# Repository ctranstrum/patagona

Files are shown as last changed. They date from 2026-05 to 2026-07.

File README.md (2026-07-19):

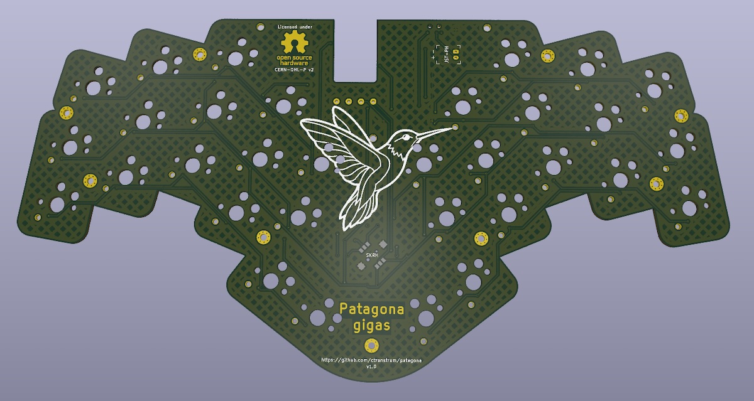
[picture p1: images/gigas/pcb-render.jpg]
Patagona gigas PCB


# Patagona Keyboards

Compact wireless ergo keyboards built around the [XIAO BLE][xiao] microcontroller
and running [ZMK][zmk] firmware with full [ZMK Studio][studio] support.
Named after the two species of giant hummingbird — the largest hummingbirds in the world.

## Features

- **Wireless** — internal LiPo battery; no cables required day to day
- **Live remapping** — ZMK Studio lets you customize your keymap over USB without recompiling firmware
- **Hotswap** — Kailh Choc sockets support both v1 and v2 switches; swap anytime
- **3D-printed case** — printable at home on any FDM printer, with split versions for smaller beds
- **Open hardware** — all source files included, licensed under [CERN-OHL-P-2.0][ohl]

## Patagona gigas

30–32 keys with a five-way joystick switch at the center,
within reach of either thumb for scroll, navigation, or mouse control.

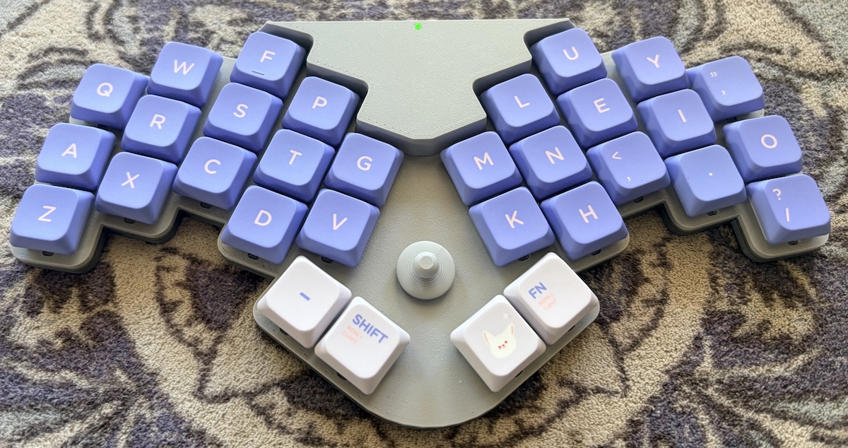
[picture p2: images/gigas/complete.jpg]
completed Patagona gigas build


[Build guide](BUILD-gigas.md) · [Printable case files][case-gigas] · [Firmware][firmware]

default Patagona gigas keymap

## Patagona chaski

40–42 keys for those who want the 3x6 layout and more thumb keys.

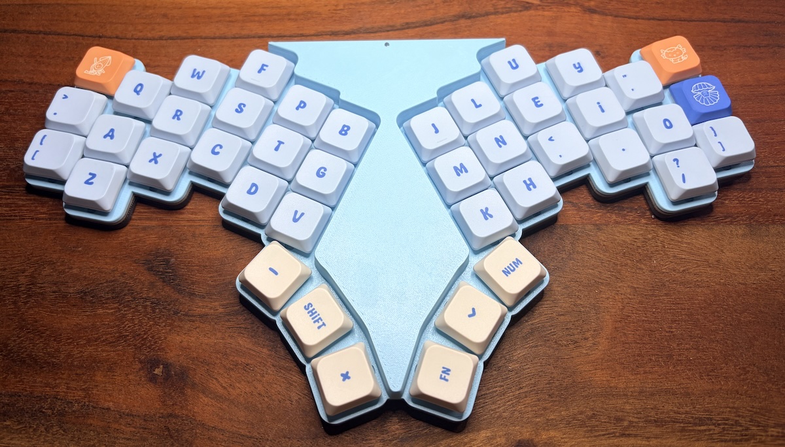
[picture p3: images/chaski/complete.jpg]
completed Patagona chaski build


[Build guide](BUILD-chaski.md) · [Printable case files][case-chaski] · [Firmware][firmware]

default Patagona chaski keymap

## Heritage

The [Patagona genus][patagona-wiki] is home to the two largest hummingbirds in the world.
_P. gigas_ is the migratory giant, ascending over 4,000 meters and traveling more than
4,000 km each way between the Chilean coast and the Peruvian Andes each year.
_P. chaski_ is its slightly larger but sedentary cousin.

These keyboards follow in the tradition of the original [Hummingbird design][pje66],
which used a XIAO SAMD21 and topped out at 30 keys
due to the maximum capacity of the 5×6 matrix allowed by the 11 pins on that board.
The Patagona boards use the XIAO BLE, whose NFC pads can be repurposed as GPIO —
adding two extra pins, enabling a 6×7 matrix and up to 42 keys.

[case-gigas]: https://github.com/ctranstrum/patagona/tree/main/cases/gigas#readme
[case-chaski]: https://github.com/ctranstrum/patagona/tree/main/cases/chaski#readme
[firmware]: https://github.com/ctranstrum/patagona-zmk
[ohl]: LICENSE.txt
[patagona-wiki]: https://en.wikipedia.org/wiki/Giant_hummingbird
[pje66]: https://github.com/PJE66/hummingbird
[studio]: https://zmk.dev/docs/features/studio
[xiao]: https://wiki.seeedstudio.com/XIAO_BLE/
[zmk]: https://zmk.dev

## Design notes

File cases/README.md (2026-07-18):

# Patagona Cases

For keyboard case files, see the keyboard-specific subdirectories:

- [Patagona chaski cases](chaski#readme)
- [Patagona gigas cases](gigas#readme)

## Five-way switch caps

This directory also contains two printable caps for the five-way switch used on the Patagona gigas:

| file | description |
| --- | --- |
| [joystick.stl](joystick.stl) | joystick-style cap (recommended) |
| [dpad.stl](dpad.stl) | dpad-style cap (experimental) |

Each cap has a corresponding `.cjs` source file that can be opened and edited at
[jscad.app](https://jscad.app) if you'd like to modify the design.

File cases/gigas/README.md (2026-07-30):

# Patagona Gigas Cases

> A quick note: these files were created through ergogen and can be
> modified and re-created if any changes are needed, which is great,
> except that the software is still a little bit buggy, so it doesn't
> make perfect STL files. Even though these can look a little strange,
> I have printed all of these files and they came out okay for me.

## Five-way switch cap

The five-way switch at the center of the Patagona gigas requires a cap to be usable.
The recommended cap is the [joystick style](../joystick.stl),
which fits snugly over the switch stem and provides a comfortable surface for navigation.

There is also an experimental [dpad style cap](../dpad.stl) available,
though after trying both, the joystick cap is the preferred option.

## Keyboard case files

### Full size printer

If you have access to your own 3D printer with a large print bed
or if you are sending the files away to be printed,
you will want to use the full size cases.

Print the following pieces:

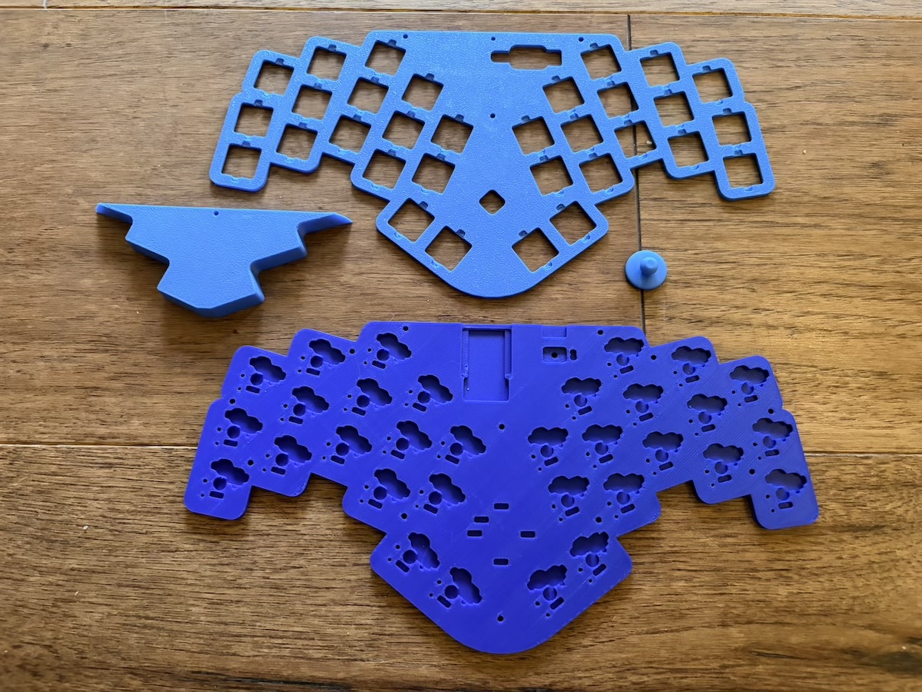
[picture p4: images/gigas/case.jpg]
case


- the bottom case
- your choice of one of the four top cases
- the battery cover
- the joystick knob

You can use the
[printer profile on makerworld](https://makerworld.com/en/models/3112971-patagona-gigas-keyboard-case#profileId-3510506)
or download the individual STL files:

| file | description |
| --- | --- |
| [bottom](bottom_case.stl) | installed below the PCB |
| [top 1+1](top_case_1_1.stl) | top case with one thumb key on each hand |
| [top 1+2](top_case_1_2.stl) | top case with one thumb key on the left and two on the right |
| [top 2+1](top_case_2_1.stl) | top case with two thumb keys on the left and one on the right |
| [top 2+2](top_case_2_2.stl) | top case with two thumb keys on each hand |
| [battery cover](battery_cover.stl) | above the top plate to cover the battery (do not print in resin) |
| [joystick knob](../joystick.stl) | knob for the central five-way switch |

Note that for best results on an FDM printer, the top plate and the battery cover should be printed upside down.

### Mini printer

If you have access to your own 3D printer
but it has a print bed too small for the full-size case,
you can print the case using these files.

Print the following pieces:

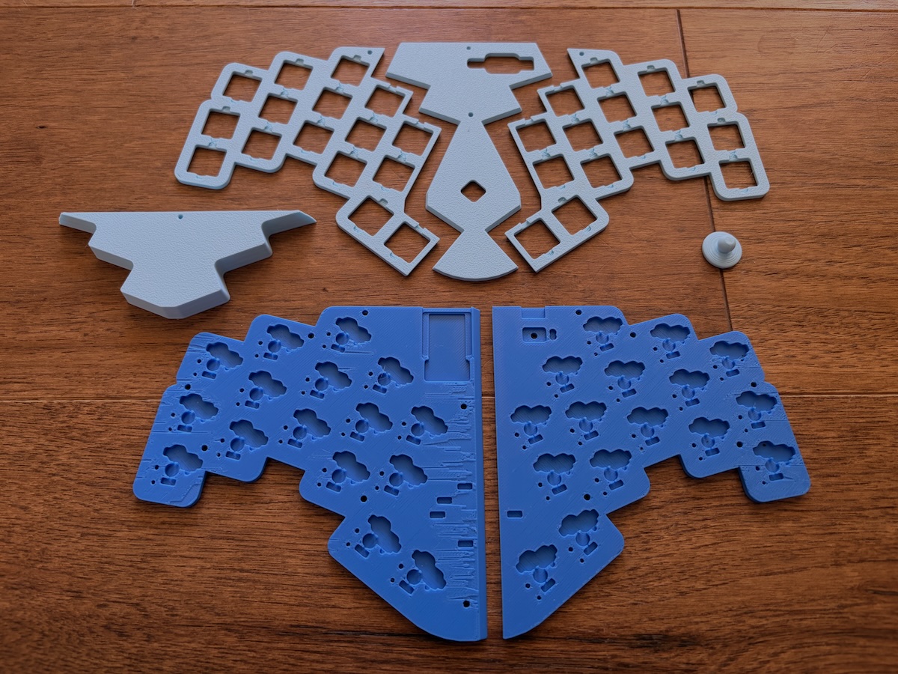
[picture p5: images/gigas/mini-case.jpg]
mini printer case


- the left and right bottom case
- the center top case
- your choice of one of the two top cases for the left hand
- your choice of one of the two top cases for the right hand
- the battery cover
- the joystick knob

You can use the
[printer profile on makerworld](https://makerworld.com/en/models/3112971-patagona-gigas-keyboard-case#profileId-3510558)
or download the individual STL files:

| file | description |
| --- | --- |
| [bottom left](bottom_case_cut_left.stl) | left bottom |
| [bottom right](bottom_case_cut_right.stl) | right bottom |
| [center](top_dovetail.stl) | center top case dovetail piece |
| [left 1](top_dovetail_left_1.stl) | left top case piece with one thumb key |
| [left 2](top_dovetail_left_2.stl) | left top case piece with two thumb keys |
| [right 1](top_dovetail_right_1.stl) | right top case piece with one thumb key |
| [right 2](top_dovetail_right_2.stl) | right top case piece with two thumb keys |
| [battery cover](battery_cover.stl) | above the top plate to cover the battery (do not print in resin) |
| [joystick knob](../joystick.stl) | knob for the central five-way switch |

Note that for best results on an FDM printer, the top plate and the battery cover should be printed upside down.

### Rectangular snap-fit case

I've also created an alternative case that uses fewer screws and instead relies on a snap-fit design
to remain securely fastened without sacrificing any additional height compared to the original sandwich design.

Unlike the sandwich-style cases, it is available only for full-size printer beds.

Print the following pieces:

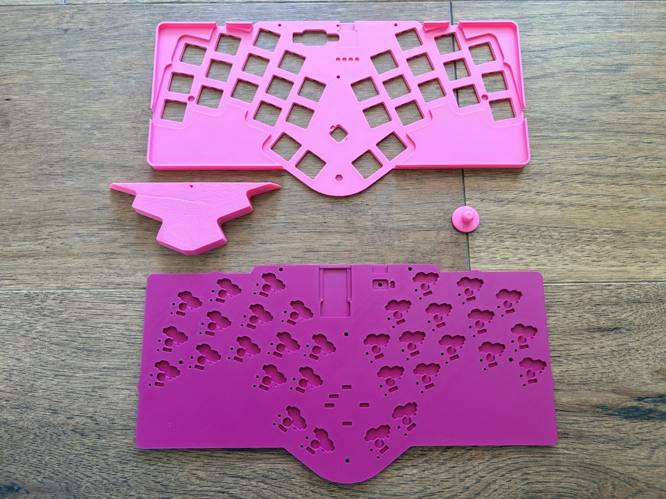
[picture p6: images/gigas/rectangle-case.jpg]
rectangle case


- the bottom case
- your choice of one of the four top cases
- the battery cover
- the joystick knob

You can use the
[printer profile on makerworld](https://makerworld.com/en/models/3112971-patagona-gigas-keyboard-case#profileId-3510571)
or download the individual STL files:

| file | description |
| --- | --- |
| [bottom](rectangle_bottom_case.stl) | bottom case |
| [top 1+1](rectangle_top_case_1_1.stl) | top case with one thumb key on each hand |
| [top 1+2](rectangle_top_case_1_2.stl) | top case with one thumb key on the left and two on the right |
| [top 2+1](rectangle_top_case_2_1.stl) | top case with two thumb keys on the left and one on the right |
| [top 2+2](rectangle_top_case_2_2.stl) | top case with two thumb keys on each hand |
| [battery cover](battery_cover.stl) | above the top case to cover the battery (do not print in resin) |
| [joystick knob](../joystick.stl) | knob for the central five-way switch |

Note that it is especially important when printing this case style on an FDM printer to place the top case
upside down in the slicer so that the top surface of the case is in direct contact with the print bed.
Otherwise you are going to have a real struggle with support removal.

## Print quality hints

For best results, use the
[printer profile on makerworld](https://makerworld.com/en/models/3112971-patagona-gigas-keyboard-case).
It has been optimized with the top pieces already placed upside down on the print bed
as well as having the layer height set to 0.1mm to ensure the best fit for the keyswitches.

When printing this case,
it should be noted that the battery cover is designed
to have heat-set inserts melted into it,
so it is not recommended to print using a resin printer
or using a material that cannot be melted easily,
unless you plan on altering the case design to use another method
to fasten the case together.

All other parts of the case can be printed in whatever material you like.

For FDM printing,
the top case and the battery cover are best printed upside down,
so that the visible part of the case is against the print bed,
giving the best top surface and requiring minimal supports to print.

If you are having trouble with some of the raised areas sagging during printing,
you can try to enable supports.
While I was able to tune my printer to get great results without supports,
if your printer is not well calibrated,
it may be worth it to enable supports and spend a little time
post-processing the prints to remove the supports prior to assembly.

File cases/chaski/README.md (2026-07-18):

# Patagona Chaski Cases

> A quick note: these files were created through ergogen and can be
> modified and re-created if any changes are needed, which is great,
> except that the software is still a little bit buggy, so it doesn't
> make perfect STL files. Even though these can look a little strange,
> I have printed all of these files and they came out okay for me.

## Keyboard case files

### Full size printer

If you have access to your own 3D printer with a large print bed
or if you are sending the files away to be printed,
you will want to use the full size cases:

| file | description |
| --- | --- |
| [bottom](bottom_case.stl) | installed below the PCB |
| [top 2+2](top_case_2_2.stl) | top case with two thumb keys on each hand |
| [top 2+3](top_case_2_3.stl) | top case with two thumb keys on the left and three on the right |
| [top 3+2](top_case_3_2.stl) | top case with three thumb keys on the left and two on the right |
| [top 3+3](top_case_3_3.stl) | top case with three thumb keys on each hand |
| [battery cover](battery_cover.stl) | above the top plate to cover the battery (do not print in resin) |

Note that for best results on an FDM printer, the top plate and the battery cover should be printed upside down.

### Mini printer

If you have access to your own 3D printer
but it has a print bed too small for the full-size case,
you can print the 3-part (plus the battery cover) top case:

| file | description |
| --- | --- |
| [center](top_dovetail.stl) | center top case dovetail piece |
| [left 2](top_dovetail_left_2.stl) | left top case piece with two thumb keys |
| [left 3](top_dovetail_left_3.stl) | left top case piece with three thumb keys |
| [right 2](top_dovetail_right_2.stl) | right top case piece with two thumb keys |
| [right 3](top_dovetail_right_3.stl) | right top case piece with three thumb keys |
| [battery cover](battery_cover.stl) | above the top plate to cover the battery (do not print in resin) |

Note that for best results on an FDM printer, the top plate and the battery cover should be printed upside down.

### Rectangular snap-fit case

I've also created an alternative case that uses fewer screws and instead relies on a snap-fit design
to remain securely fastened without sacrificing any additional height compared to the original sandwich design.

Unlike the sandwich-style cases, it is available only for full-size printer beds.

| file | description |
| --- | --- |
| [bottom](rectangle_bottom_case.stl) | bottom case |
| [top 2+2](rectangle_top_case_2_2.stl) | top case with two thumb keys on each hand |
| [top 2+3](rectangle_top_case_2_3.stl) | top case with two thumb keys on the left and three on the right |
| [top 3+2](rectangle_top_case_3_2.stl) | top case with three thumb keys on the left and two on the right |
| [top 3+3](rectangle_top_case_3_3.stl) | top case with three thumb keys on each hand |
| [battery cover](battery_cover.stl) | above the top case to cover the battery (do not print in resin) |

Note that it is especially important when printing this case style on an FDM printer to place the top case
upside down in the slicer so that the top surface of the case is in direct contact with the print bed.
Otherwise you are going to have a real struggle with support removal.

## Print quality hints

When printing this case,
it should be noted that the battery cover is designed
to have heat-set inserts melted into it,
so it is not recommended to print using a resin printer
or using a material that cannot be melted easily,
unless you plan on altering the case design to use another method
to fasten the case together.

All other parts of the case can be printed in whatever material you like.

For FDM printing,
the top case and the battery cover are best printed upside down,
so that the visible part of the case is against the print bed,
giving the best top surface and requiring minimal supports to print.

If you are having trouble with some of the raised areas sagging during printing,
you can try to enable supports.
While I was able to tune my printer to get great results without supports,
if your printer is not well calibrated,
it may be worth it to enable supports and spend a little time
post-processing the prints to remove the supports prior to assembly.

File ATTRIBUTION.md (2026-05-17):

# Graphics images

The hummingbird image on the PCB is
by Cimrin from [Noun Project](https://thenounproject.com/browse/icons/term/hummingbird/) (CC BY 3.0)

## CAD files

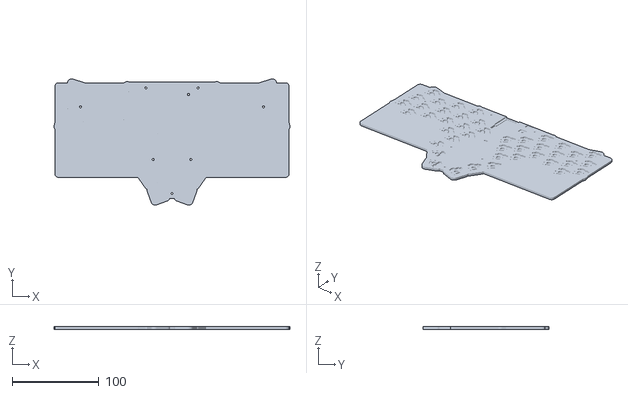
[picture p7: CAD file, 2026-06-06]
cases/chaski/rectangle_bottom_case.stl
271.6 x 145.2 x 3.00

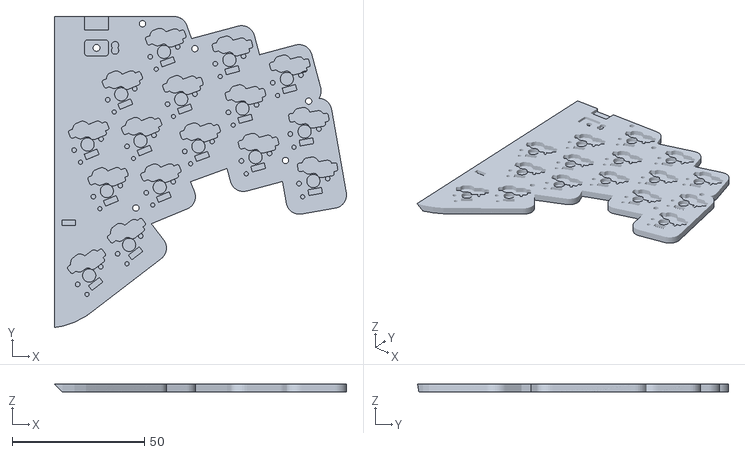
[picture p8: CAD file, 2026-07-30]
cases/gigas/bottom_case_cut_right.stl
110.3 x 117.4 x 3.00

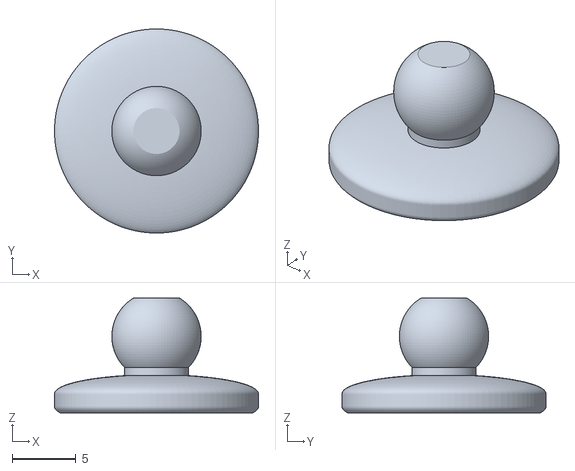
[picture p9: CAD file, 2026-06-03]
cases/joystick.stl
16.0 x 16.0 x 9.00

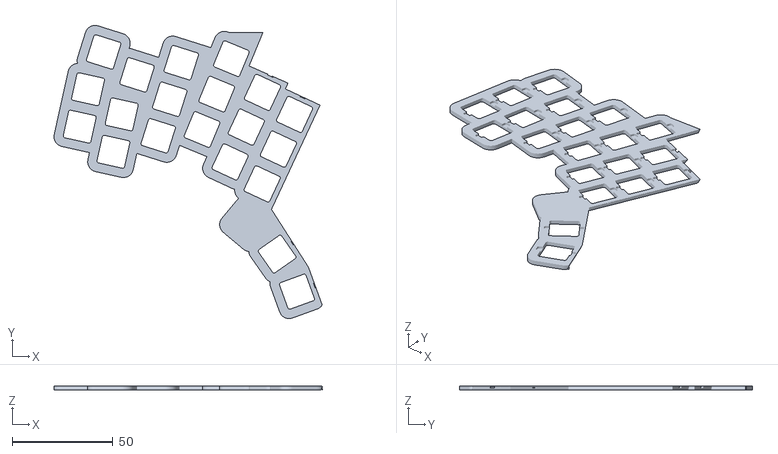
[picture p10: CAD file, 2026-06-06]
cases/chaski/top_dovetail_left_2.stl
161.5 x 145.2 x 2.20

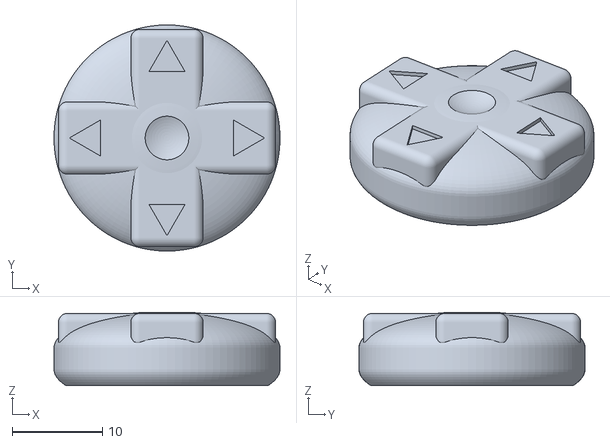
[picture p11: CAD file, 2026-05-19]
cases/dpad.stl
25.0 x 25.0 x 8.12

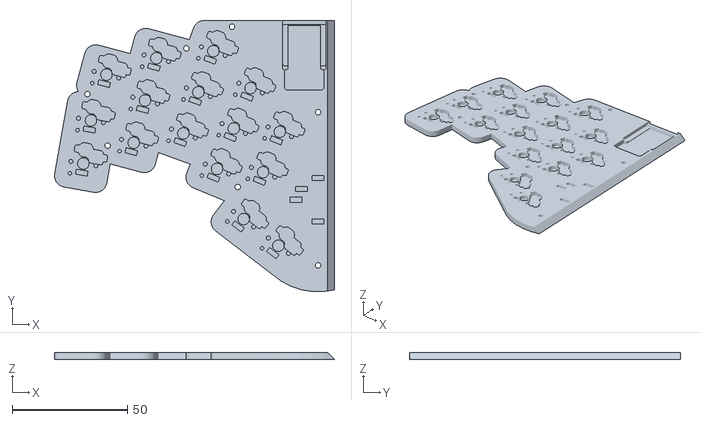
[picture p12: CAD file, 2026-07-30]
cases/gigas/bottom_case_cut_left.stl
121.5 x 117.7 x 3.00

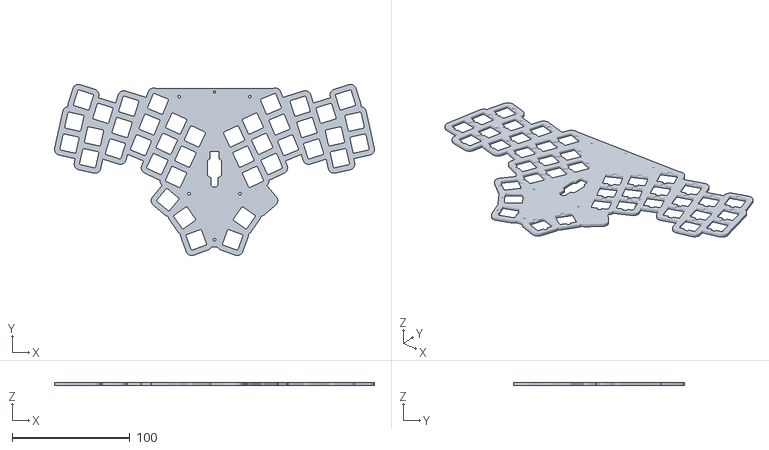
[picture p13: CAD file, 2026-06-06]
cases/chaski/top_case_3_2.stl
271.6 x 145.2 x 2.20

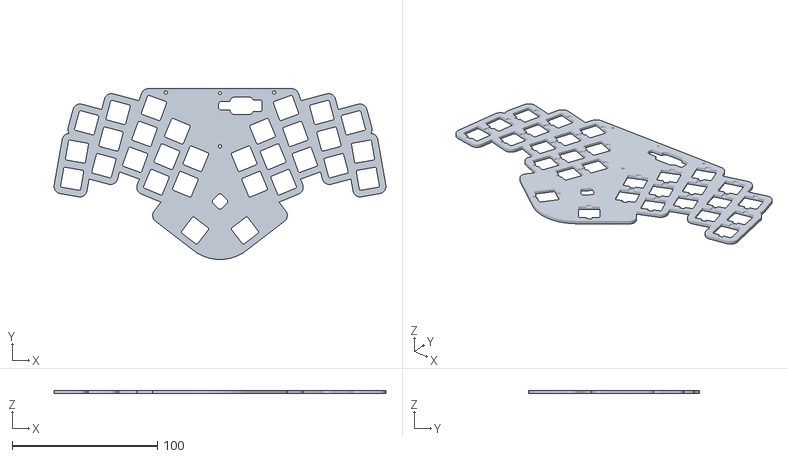
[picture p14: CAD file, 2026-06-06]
cases/gigas/top_case_1_1.stl
228.8 x 117.7 x 2.20

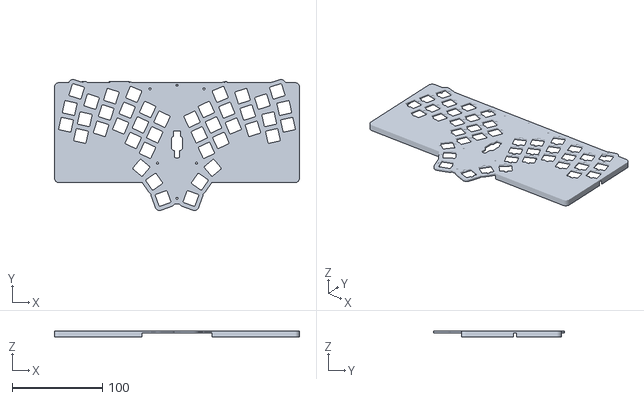
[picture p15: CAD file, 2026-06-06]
cases/chaski/rectangle_top_case_3_3.stl
271.7 x 145.2 x 6.80

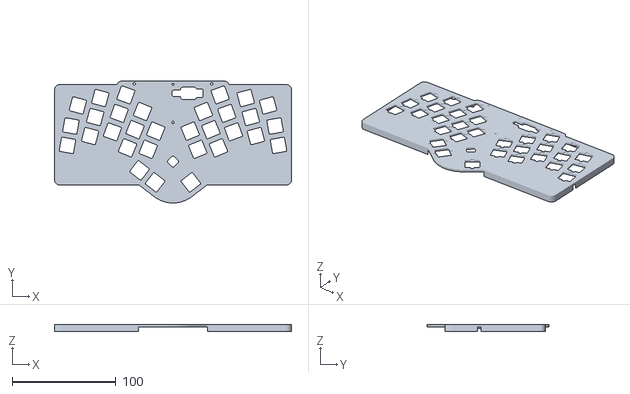
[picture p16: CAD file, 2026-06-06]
cases/gigas/rectangle_top_case_2_1.stl
228.8 x 117.7 x 6.80

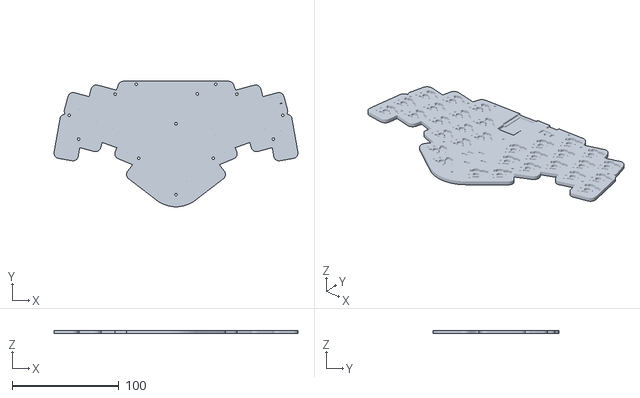
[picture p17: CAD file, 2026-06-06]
cases/gigas/bottom_case.stl
228.8 x 117.7 x 3.00

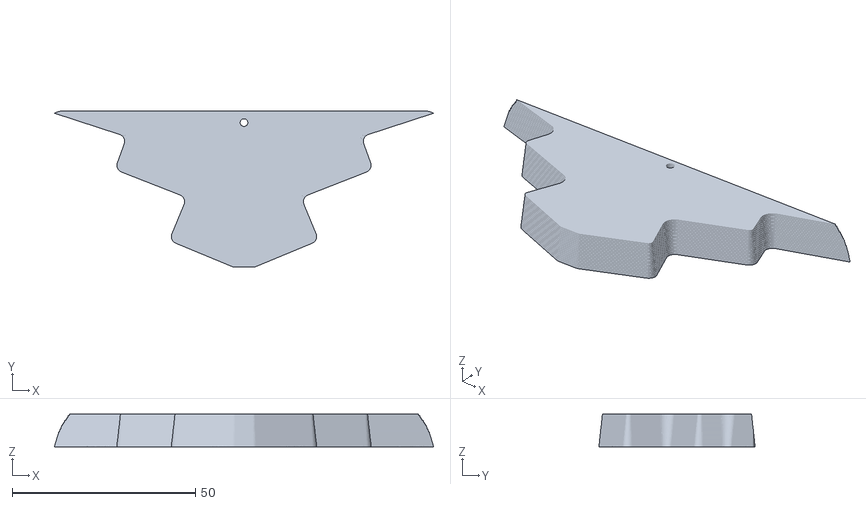
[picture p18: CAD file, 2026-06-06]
cases/gigas/battery_cover.stl
103.5 x 42.7 x 9.00

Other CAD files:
cases/chaski/rectangle_top_case_2_2.stl
cases/chaski/top_case_2_2.stl
cases/gigas/rectangle_top_case_1_2.stl
cases/chaski/rectangle_top_case_3_2.stl
cases/gigas/rectangle_top_case_1_1.stl
cases/chaski/rectangle_top_case_2_3.stl
cases/chaski/battery_cover.stl
cases/chaski/bottom_case.stl
cases/chaski/top_case_2_3.stl
cases/chaski/top_case_3_3.stl
cases/chaski/top_dovetail.stl
cases/chaski/top_dovetail_left_3.stl
cases/chaski/top_dovetail_right_2.stl
cases/chaski/top_dovetail_right_3.stl
cases/gigas/rectangle_bottom_case.stl
cases/gigas/rectangle_top_case_2_2.stl
cases/gigas/top_case_1_2.stl
cases/gigas/top_case_2_1.stl
cases/gigas/top_case_2_2.stl
cases/gigas/top_dovetail.stl
cases/gigas/top_dovetail_left_1.stl
cases/gigas/top_dovetail_left_2.stl
cases/gigas/top_dovetail_right_1.stl
cases/gigas/top_dovetail_right_2.stl

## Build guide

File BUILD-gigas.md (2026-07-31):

# Patagona gigas Build Guide

If this is your first time building a custom keyboard,
you should do two things before attempting this build.

- watch a few [soldering][how-to-solder] [tutorials][soldering101]
- read through a detailed build guide like
  the one for the [splitkb.com Aurora Series][splitkb-build-guide]

The remainder of this build guide will assume a basic familiarity with the process
and will only hit upon specific items that may be different or important to note while
building the Patagona gigas.

## Bill of materials

| Qty | Description |
| --- | --- |
| 1 | Gigas PCB (can be printed by uploading the [zip file][gigas-gerber] to [JLC][jlcpcb]) |
| 3 | [3D printed cases][case] |
| 1 | [XIAO BLE][xiao] |
| 1 | [SMD 5x5x3 tactile switch][reset] for the reset button (similar to [this][pts526] or [this][ts18]) |
| 1 | [Alps SSSS811101 SPDT slide switch][power] for the battery on/off |
| 1 | [3.7v 400mAh 802525 LiPo battery][battery] or smaller (max internal space: 8x28x29mm) |
| 1 | [JST PH-2 battery jack][jst] |
| 1 | Alps Alpine [SKRHADE010 five-way switch][fiveswitch] |
| 30-32  | SOD-123 [1N4148W SMD diodes][sod123] |
| 30-32  | Kailh [choc hot swap sockets][sockets] |
| 30-32  | [Choc v1][chocv1] or [v2 switches][chocv2] of your choice |
| 30-32  | [Low profile choc v1][chockeycaps] or [v2 keycaps][mxkeycaps] of your choice |
| 9 (3)  | [M2 x 6mm countersunk screws][screws6mm] |
| 9 (3)  | [M2 hex nuts][hexnuts] |
| 3 | [M2 x 10mm countersunk screws][screws10mm] |
| 3 | [M2 heat-set inserts 3mm x 3mm][heatset] |
| 10 (8) | [6mm x 1.5mm bumpons][bumpons] |
| ~1cm | [1.75mm transparent 3D printer filament][filament] for the "fiber optic" led light guide |
| 4 | short (1-2cm) pieces of [26 gauge electrical wire][wire] |

**Note**: When assembling a gigas build in a rectangle case, you will use fewer 6mm screws, hex nuts, and bumpons.
The quantities for the rectangle case are given in parentheses.

## Useful equipment

You will need:

- a [soldering iron][pinecil]
- some [good quality solder][kester]
- precision tweezers
- wire cutter / stripper

You should ideally have access to:

- a [heat-set insert tool][heatsettool]
- a decent hands-free magnifying glass
- isopropyl alcohol and an old toothbrush

## Getting the PCB

The PCB can be easily ordered from a circuit board manufacturer with an online store.
I used [JLC][jlcpcb] because--at least at the time of my order--their prices are unbeatable.

To order, you can simply upload the [gerber zip file][gigas-gerber] to their website,
accept all of the defaults, and wait a week or two for the boards to arrive.

However, the minimum order at JLC is 5 copies, so you'll likely end up
with 4 extra PCBs. I don't really have any advice for what to do with
the extras, but you maybe could give one to a friend!

A couple items that you may want to customize:

- the color of the board; I printed mine in black
- HASL can be lead-free if you are also using lead-free solder, or you can splurge for ENIG, but it's definitely not required

gigas pcb render

## Getting the case

If you have access to a 3D printer, the [case][case] is very easy to print yourself.

If you don't have your own printer, no worries.
You will probably want to send in your print order around the same time you order the PCB.
I've used [JLC][jlc3dp] in the past with good results.

Just remember that you should print the battery cover
in nylon or PLA rather than resin,
though all other parts of the case can be printed in resin.
The reason for this is that the design calls for heat-set inserts
to be melted into that piece, and resin doesn't work for that.

## General soldering order

Although you can work in any order you prefer,
I like to start with the smaller components, then move to the larger,
and finish with bulky items that go on the top of the board.

So, the order I install:

### Installed on the bottom of the board

- diodes
- hotswap sockets
- power switch
- reset switch
- xiao
- reset and battery wire connections to xiao

### Installed on the top of the board

- jst (inserted from the top, soldered from the bottom)
- five-way switch (the only component installed entirely from the top of the board)

## Step-by-step instructions

Let's get started, shall we?

### Solder the diodes

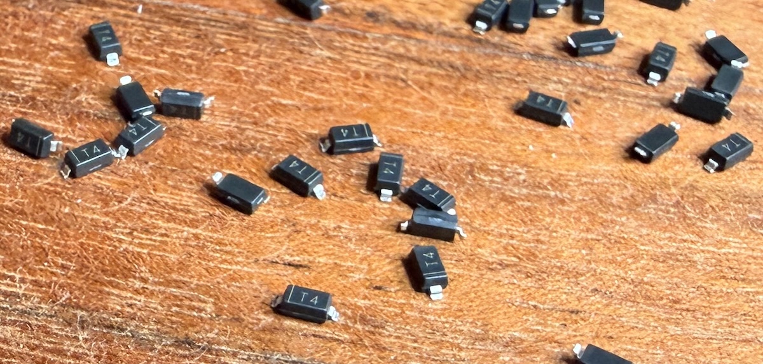
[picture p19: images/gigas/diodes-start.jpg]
diodes and PCB ready to begin soldering


Diodes are directional components, and must be soldered in the correct orientation.

To determine the orientation, look for a line printed on one edge of the diode.
You may need to use a magnifier glass and adjust the angle of light hitting the diode
in order to see it clearly.
Once you find the line on the diode, you can align it with the silk-screened line on the PCB,
and then solder with both lines on the same side.

All diodes are installed in roughly the same direction on the board, with the line on the right.

To easily install a diode, first place a small amount of solder onto one of the diode pads.

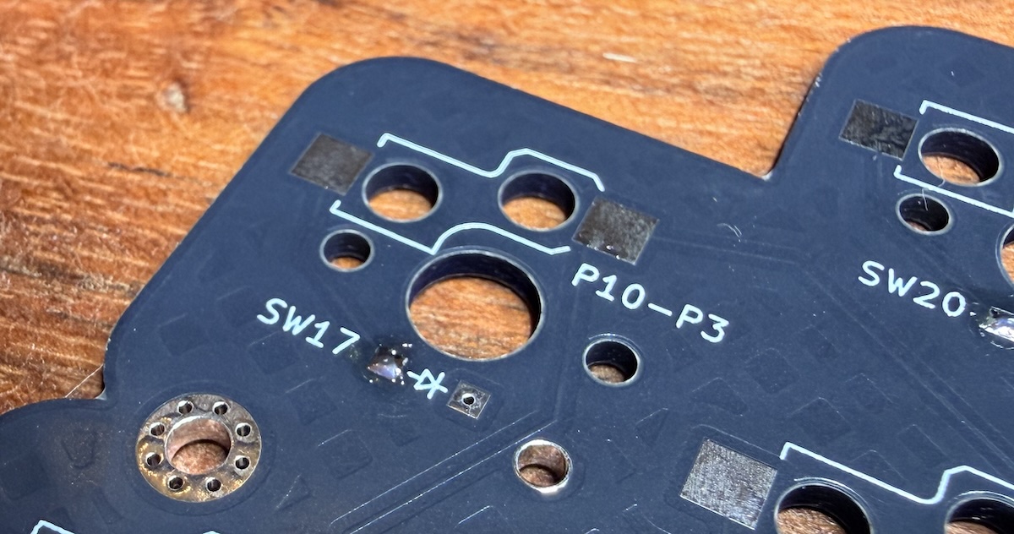
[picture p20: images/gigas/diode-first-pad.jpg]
diode with one pad soldered, ready to place


Then grab the diode with tweezers and orient it correctly.
Reheat the soldered pad, then slide the diode into place.
Remove the heat, and when the solder cools, release the diode.

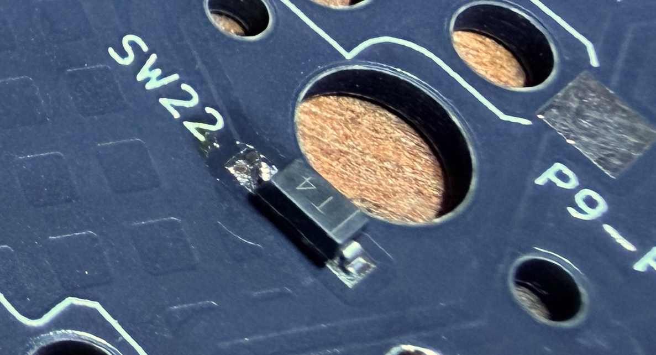
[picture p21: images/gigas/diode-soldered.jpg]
diode with both legs soldered in place


With one leg installed, you can apply solder to the other leg.

Complete all diodes, being sure to double-check that they are all oriented
correctly and both legs are soldered before moving to the next step.

### Solder the hotswap sockets

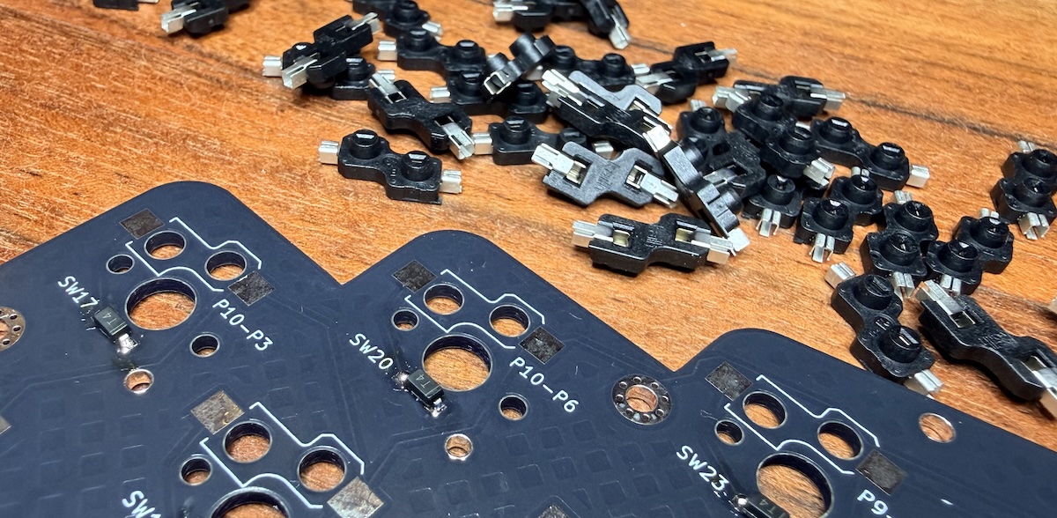
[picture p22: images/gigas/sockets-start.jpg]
sockets ready to be soldered to the PCB


While hotswap sockets will work the same way electrically no matter which way they are installed,
the tolerances of the case are such that you should take care to install these
according to the markings on the PCB as well.

In the following picture, the blue box on SW20 shows the silkscreen line before
a hotswap socket is installed, the green box on SW22 shows a hotswap socket in the
correct orientation where the silkscreen line is mostly hidden by the edges of the socket,
and the red box on SW19 shows an incorrectly oriented
hotswap socket, where the silkscreen line is clearly visible poking out around the
angled edges of the socket.

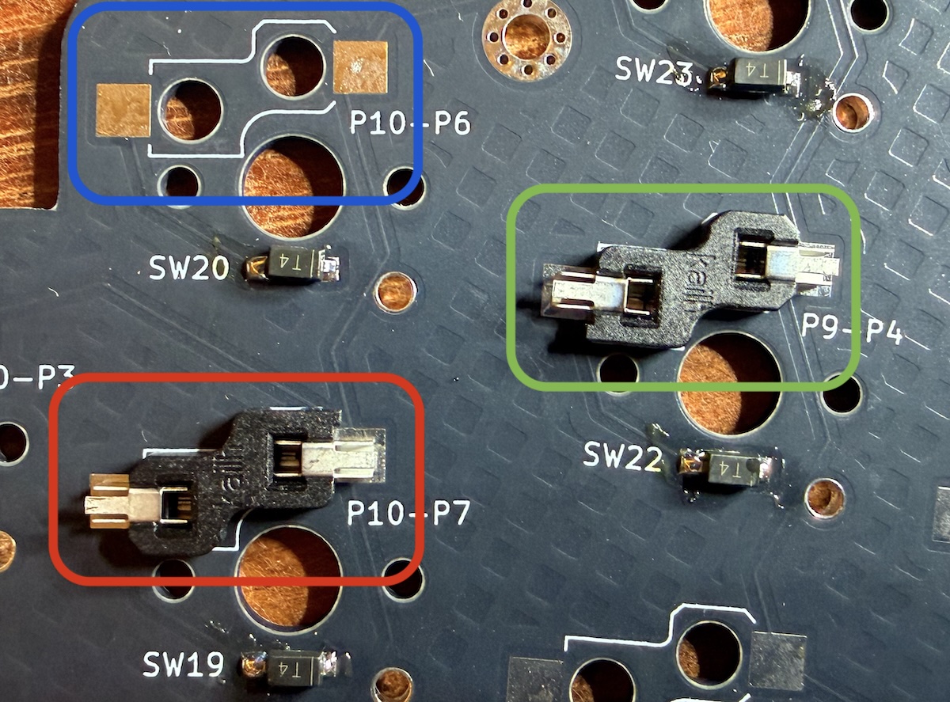
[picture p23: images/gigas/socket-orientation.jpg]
three sockets showing correct and incorrect orientation


Place the hotswap socket into the PCB holes,
being sure that the silkscreen on the PCB matches the orientation of the socket,
then apply solder to one of the legs.

This will take a lot more solder than the diode did, but be careful not to get carried away.
The solder should not overflow the pad or rise above the socket.

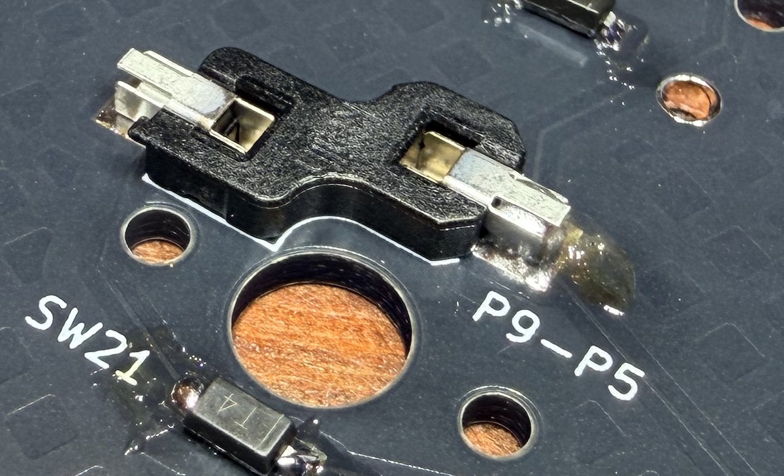
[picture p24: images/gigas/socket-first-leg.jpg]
hotswap socket with first leg soldered


Once done, use tweezers to hold the socket in place until the solder cools.

Flip the board around and solder the other pad.

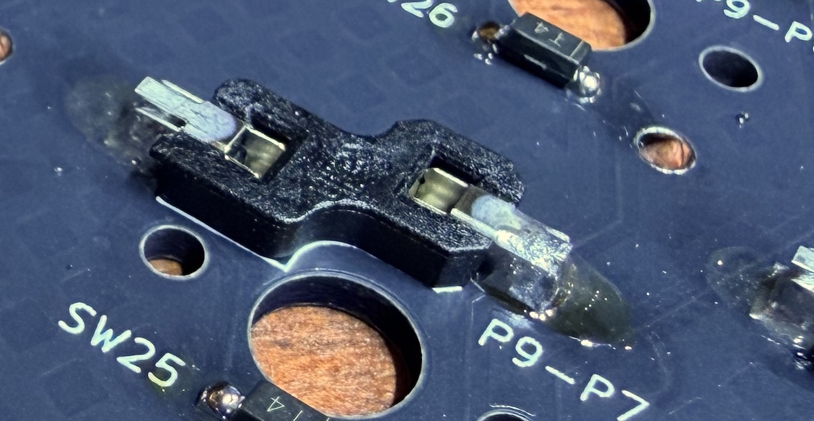
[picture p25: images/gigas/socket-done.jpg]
hotswap socket with both legs soldered


Solder all the sockets on the board.

### Solder the power switch

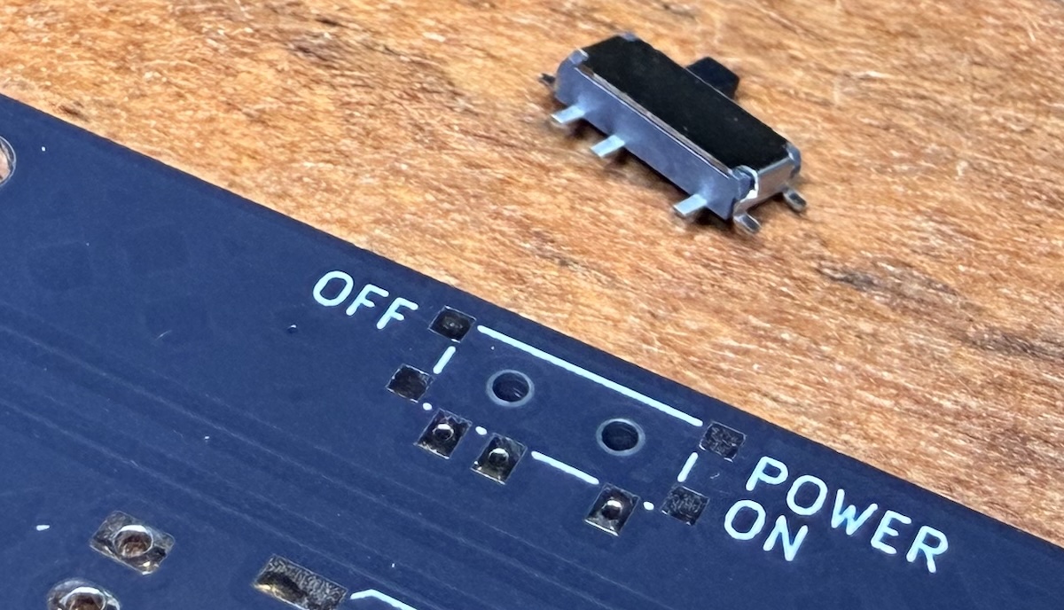
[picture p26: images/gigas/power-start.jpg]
power switch ready to be soldered


To solder the power switch, first apply a bit of solder to one of the pads.

Holding the power switch in place with tweezers, reheat the soldered pad
and align the power switch. Remove the heat, and release the power switch
only after the solder has cooled.

Once satisfied with the placement, solder each of the other pads, being very careful
not to allow the solder to connect neighboring pads.

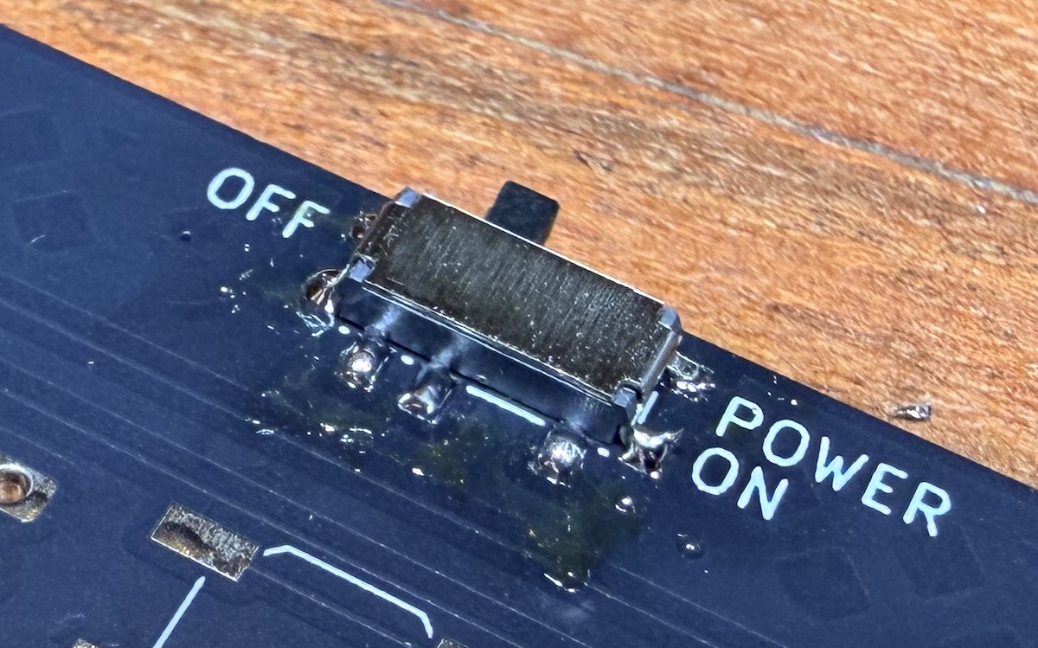
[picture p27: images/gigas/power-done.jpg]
power switch fully soldered


### Solder the reset switch

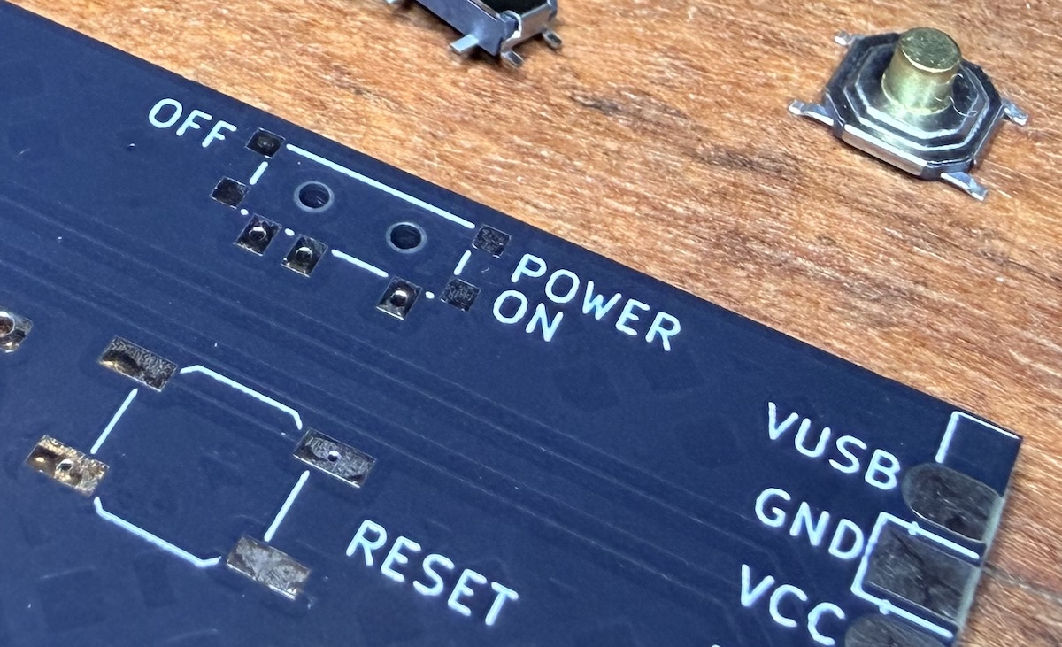
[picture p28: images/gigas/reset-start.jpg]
reset switch ready to be soldered


The reset switch follows the same process,
though it can require a little more attention to align it correctly.

Apply solder to one pad,
use tweezers to slide the reset switch into place while reheating the solder,
and remove the heat when you are satisfied with the alignment.

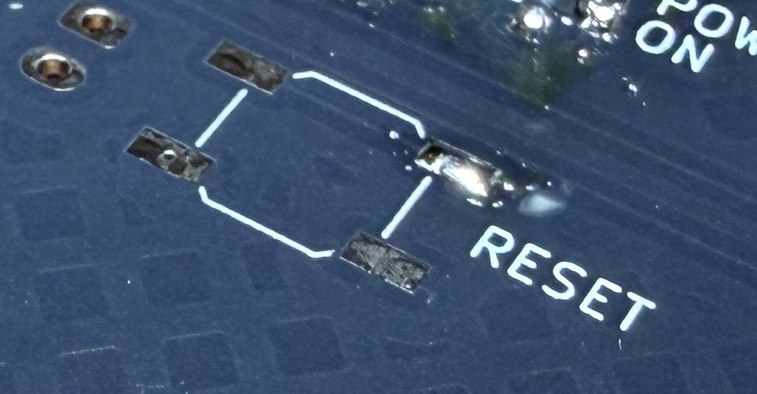
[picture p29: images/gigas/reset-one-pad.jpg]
first pad ready to receive the reset switch


Complete the remaining pads.

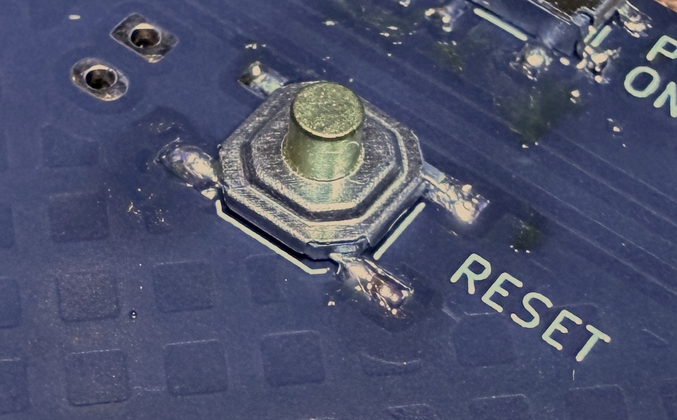
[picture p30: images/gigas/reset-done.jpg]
reset switch fully soldered


### Solder the xiao

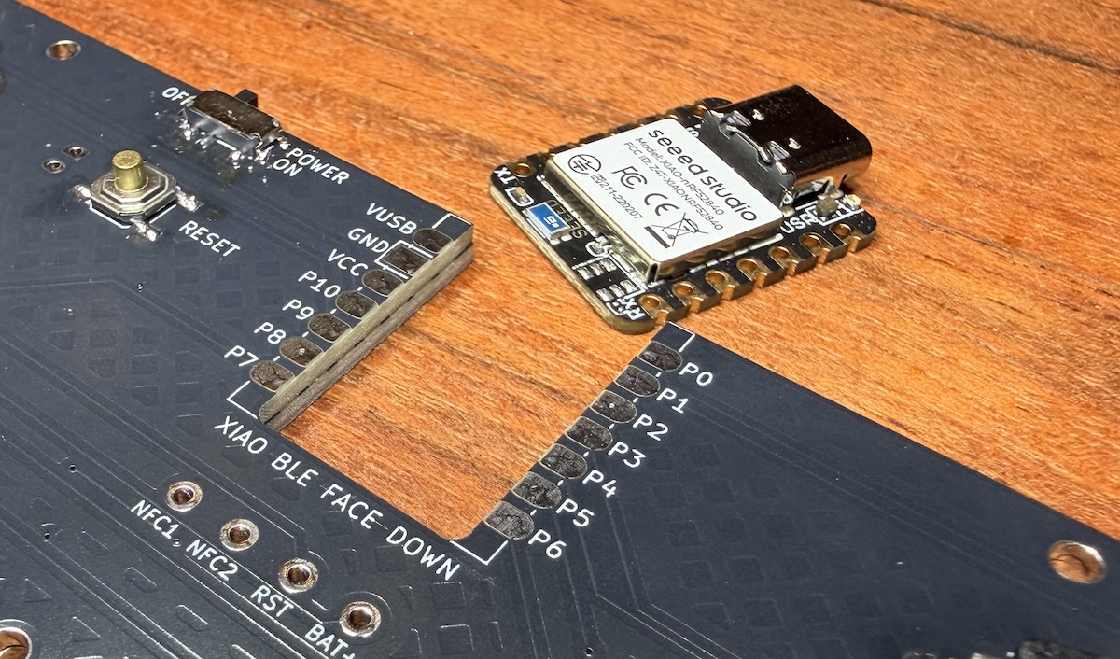
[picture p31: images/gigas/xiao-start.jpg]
PCB elevated for installation of the XIAO


The xiao is installed upside down,
with the components on top of the xiao extending
into and beyond the space of the PCB.

Because of this, the xiao will need a little space under it,
since it is thicker than the PCB.
I like to stack another board below it to provide that space,
but any method of elevating the board will work.

Begin by placing a little solder on one of the corner pads.
Put the xiao in place, reheat the soldered pad,
and ensure the correct placement of the xiao before removing the heat.

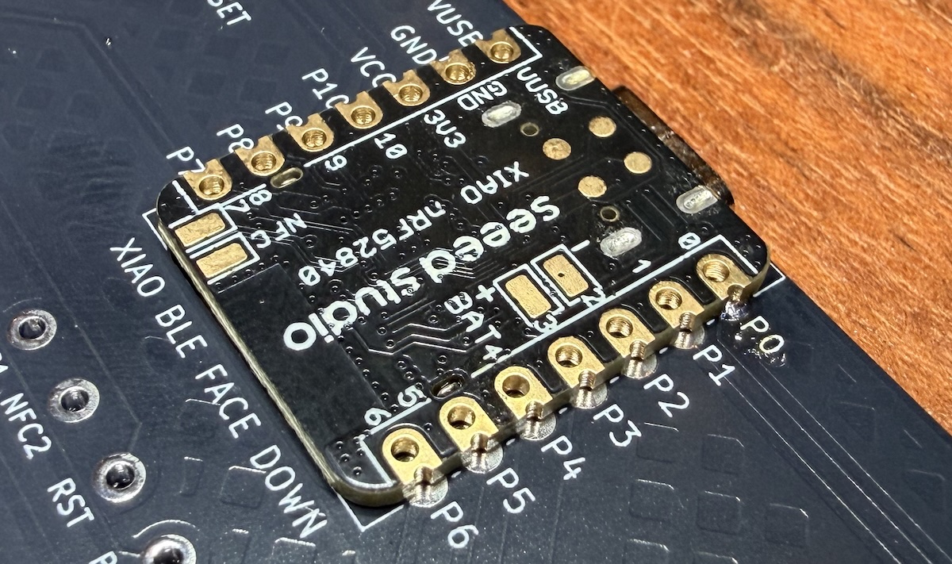
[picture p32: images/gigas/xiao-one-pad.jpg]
xiao with one corner pad soldered


Once the solder cools and you are satisfied that the xiao is in the correct place,
solder the opposite corner. It can be a little tricky to get heat on both the
pad of the PCB as well as the xiao's pad, so take your time, use plenty of heat,
and wait until you see the solder moving below the xiao and filling a bit of the
through-hole.

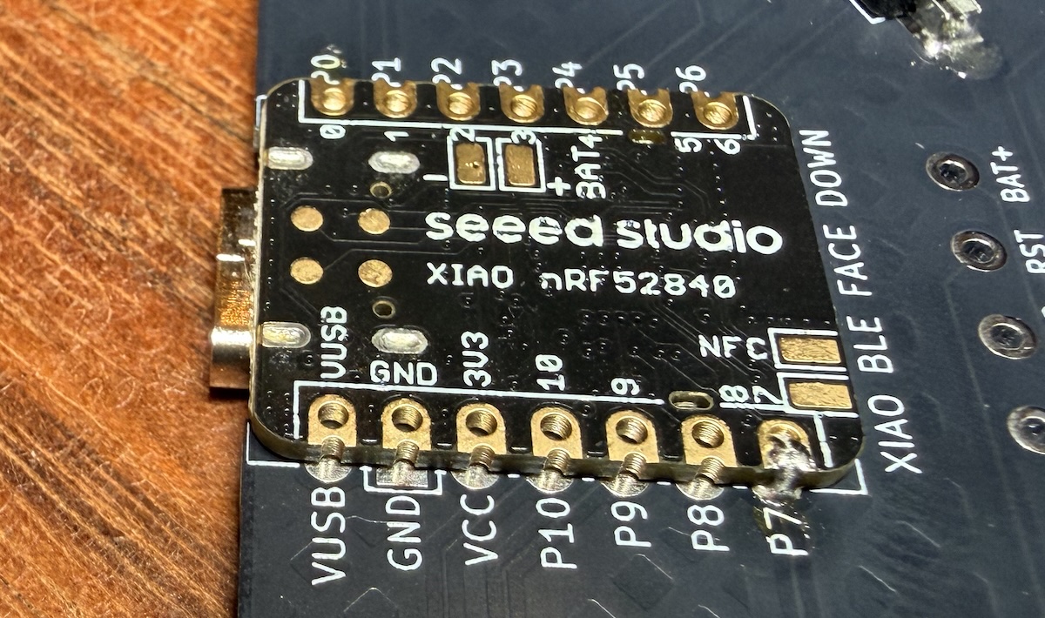
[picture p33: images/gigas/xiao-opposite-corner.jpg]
xiao with opposite corner pad soldered


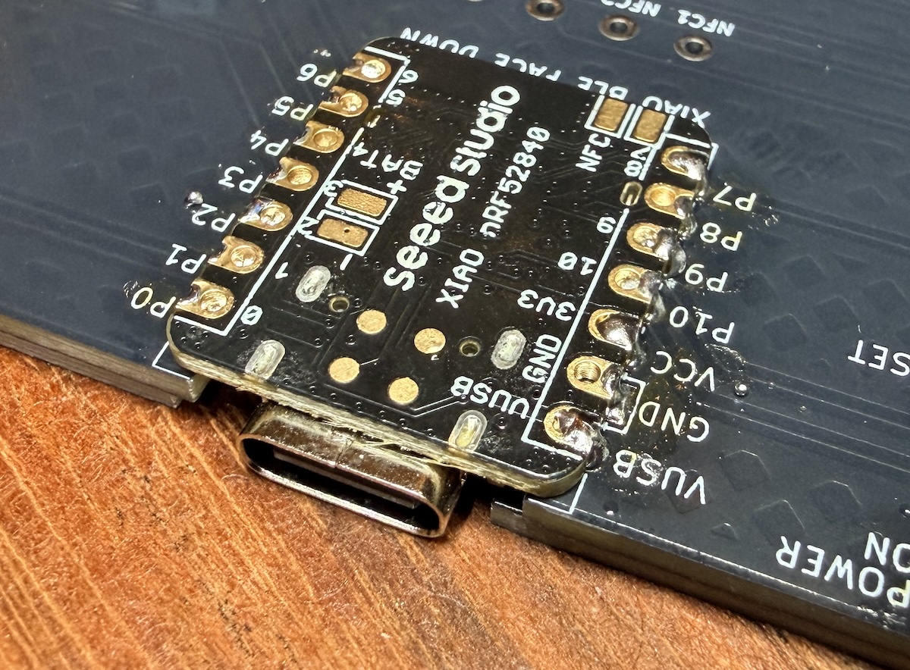
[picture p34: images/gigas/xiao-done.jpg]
xiao fully soldered to PCB


Repeat this process until all the pads of the xiao are soldered well to the board.
I also usually re-solder the first pad I did,
since it likely has the least amount of solder on it compared to all the others.

### Solder the xiao connections

Begin by cutting a short piece of wire a little bit longer than needed to connect the pad to the through-hole.

For the power connection, this connects the BAT+ hole on the PCB with the BAT+ pad on the back of the xiao.

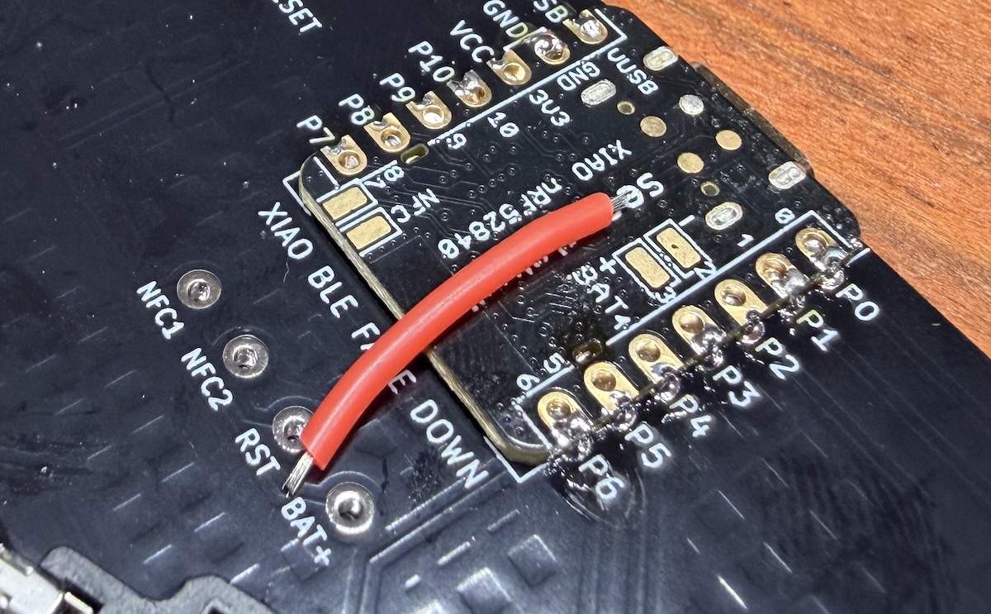
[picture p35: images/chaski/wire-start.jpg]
BAT+ wire ready to connect xiao to PCB


Trim about 1.5mm of shielding off each end of the wire, and then solder the wire.
I like to start with the end on the xiao's pad, and once that is in place,
stick the other end into the through hole and solder there as well.

The reset wire connects the RST hole on the PCB to the unlabeled reset pad on the back of the xiao.

Even though it's unlabeled, it's not difficult to find.
There are four circular pads near the USB port at the top of the xiao.

Location of the RST pad on the XIAO BLE:

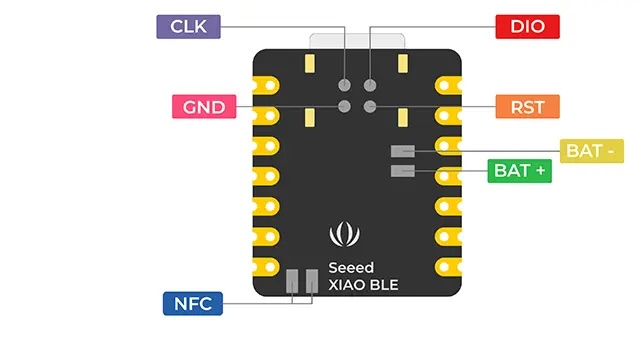
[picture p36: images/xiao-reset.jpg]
location of RST pad on the back of the XIAO BLE


Install it using the same method as the BAT+ wire.

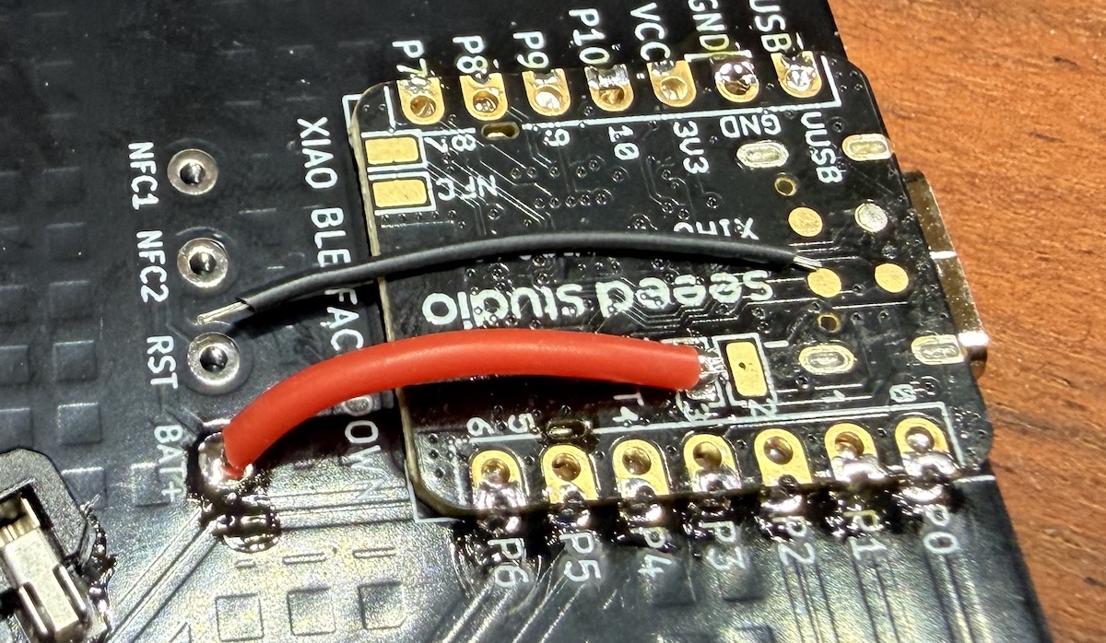
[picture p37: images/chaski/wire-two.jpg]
RST wire connecting xiao to PCB


The final two wires connect the NFC1 and NFC2 holes on the PCB to the NFC pads on the back of the xiao.
The xiao has two NFC pads near each other, though only one of them is labeled.
Install these wires so that they run parallel to each other:
NFC2 on the PCB connects to the right NFC pad on the xiao,
and NFC1 on the PCB connects to the left NFC pad on the xiao.
Install NFC2 first, then NFC1.

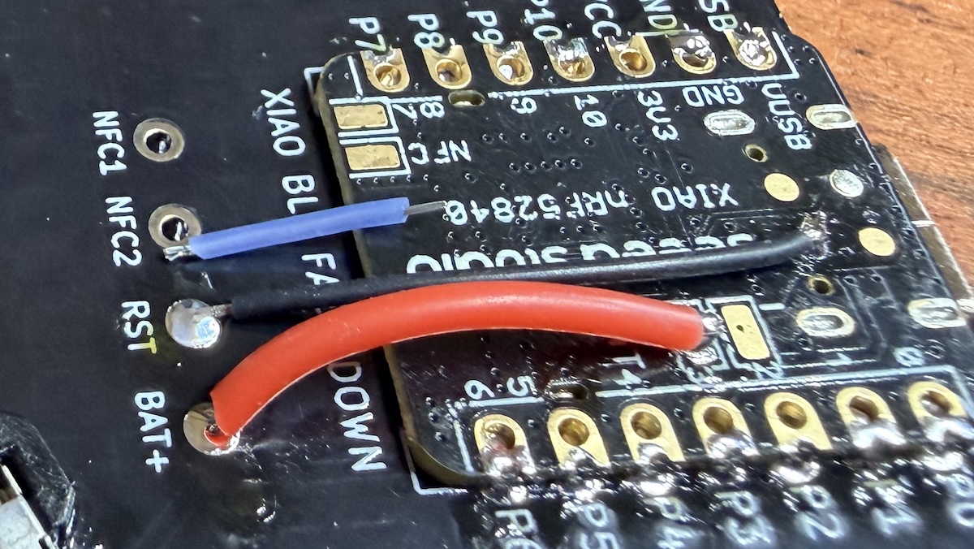
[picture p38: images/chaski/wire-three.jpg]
NFC2 wire cut and ready to install


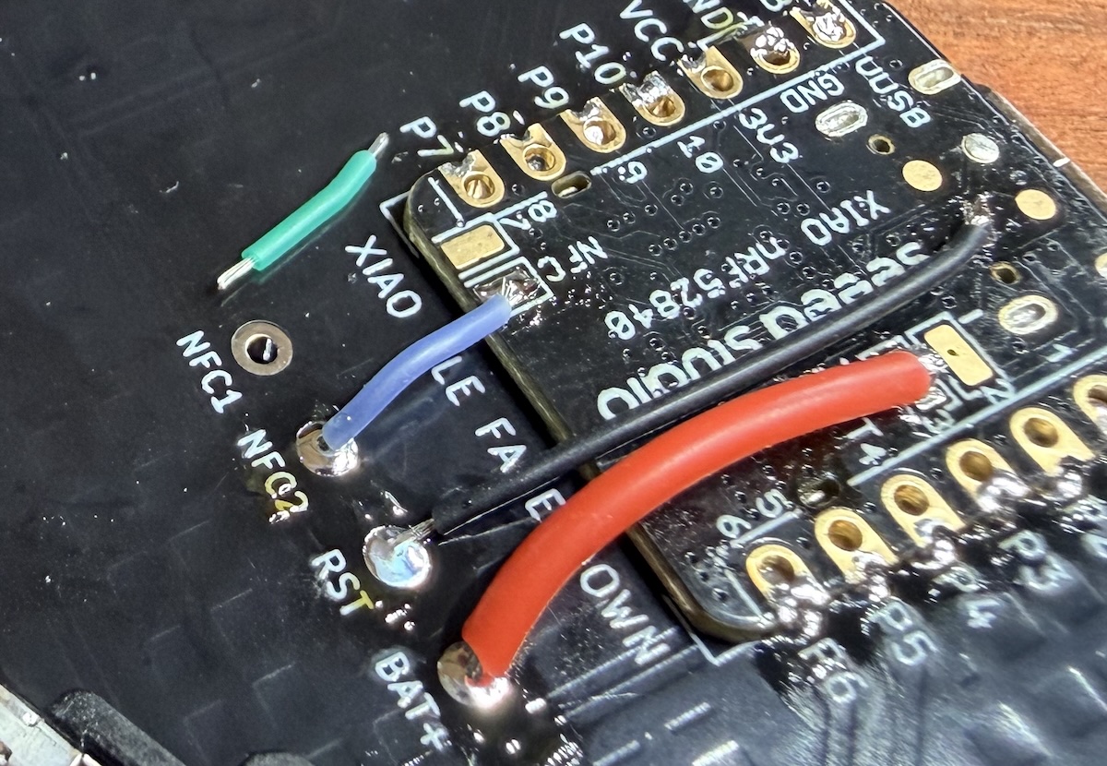
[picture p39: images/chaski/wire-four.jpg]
NFC2 installed, NFC1 wire cut and ready to install


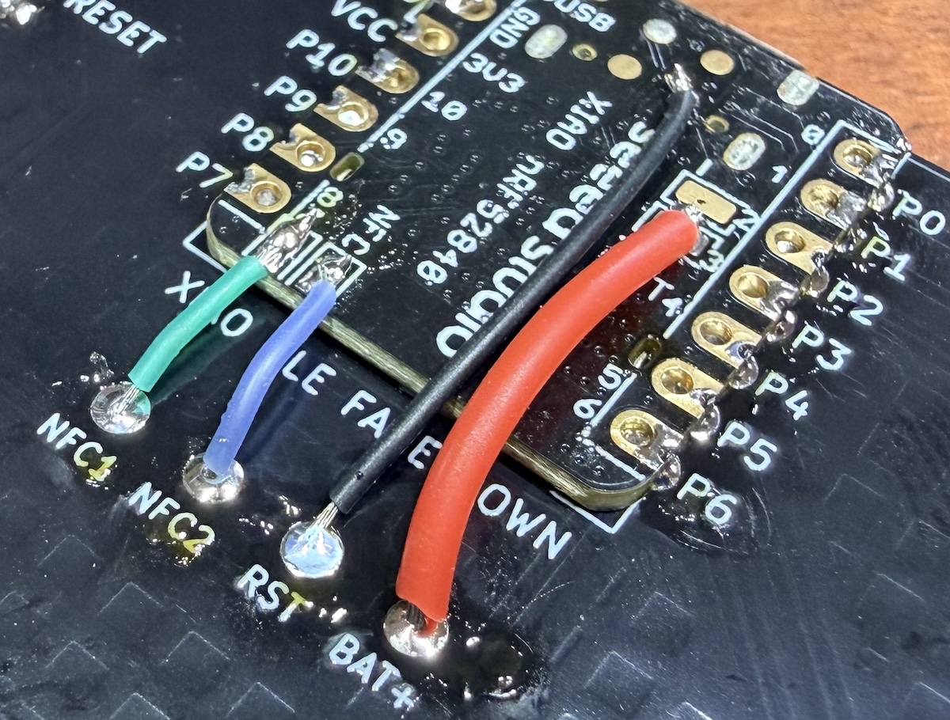
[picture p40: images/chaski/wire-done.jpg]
all four wires complete


### Solder the JST connector

Unlike all components so far,
the JST connector needs to be inserted into place from the opposite side of the board.

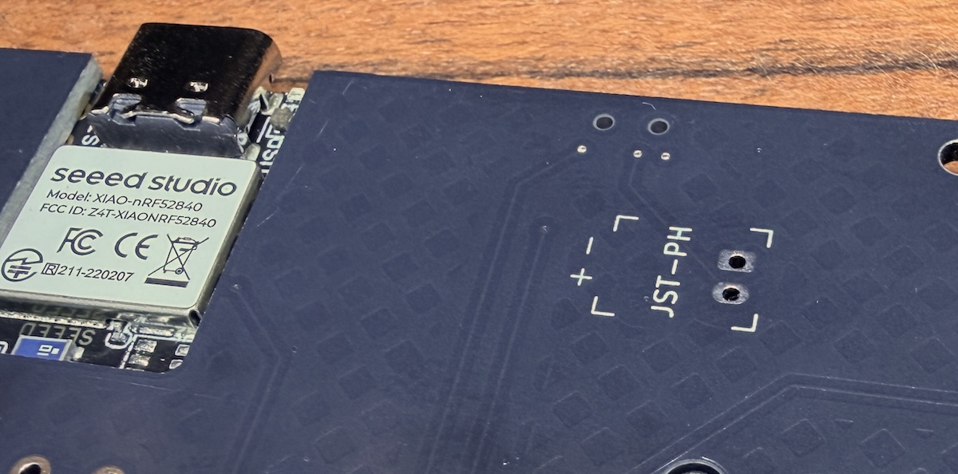
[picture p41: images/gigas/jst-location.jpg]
JST connector location on the front of the PCB


Once in place, secure it temporarily with a little tape
while you solder the legs on the other side of the board.

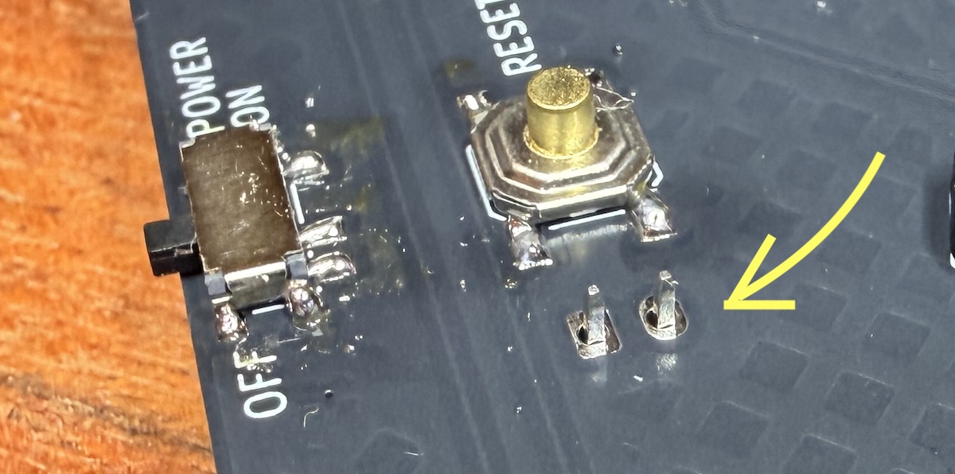
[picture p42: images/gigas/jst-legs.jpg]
JST legs poking through the back of the PCB


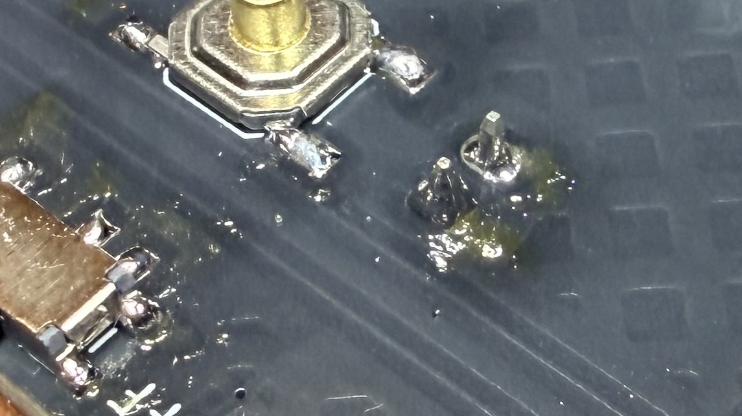
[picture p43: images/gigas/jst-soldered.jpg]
JST legs fully soldered on the back of the PCB


Remove the tape when done.

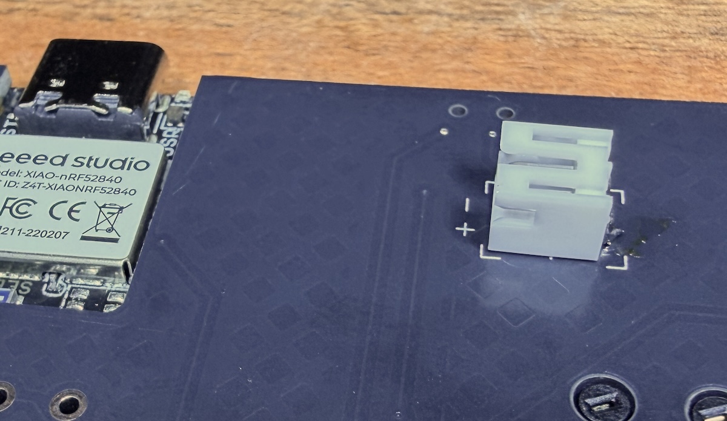
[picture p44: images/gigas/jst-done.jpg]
completed JST connector on the front of the board


### Solder the five-way switch

The five-way switch is the only component soldered entirely from the front of the board.
It has guide bosses on its underside that insert into corresponding holes in the PCB,
which keeps it properly aligned while you solder.

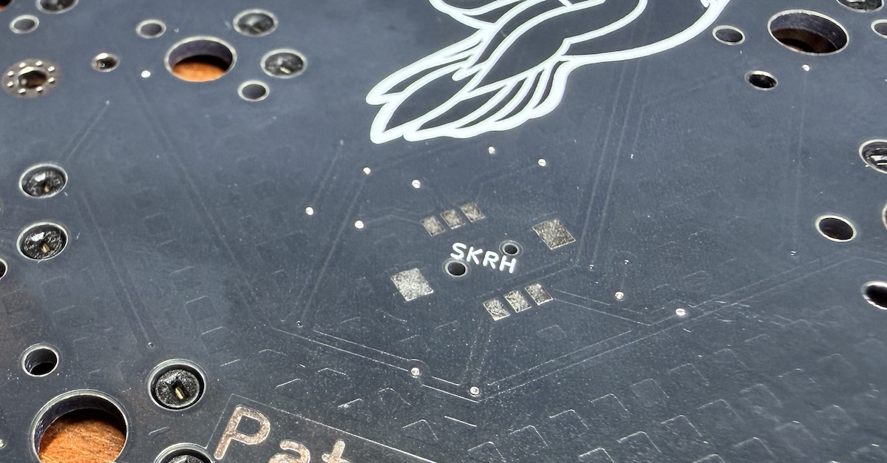
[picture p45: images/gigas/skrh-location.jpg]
five-way switch ready to be soldered


Begin by inserting the guide bosses into the holes in the PCB.
Then solder the two large ground pads on either side of the switch first.
These will hold the switch firmly in place and prevent it from shifting
while you complete the finer work.

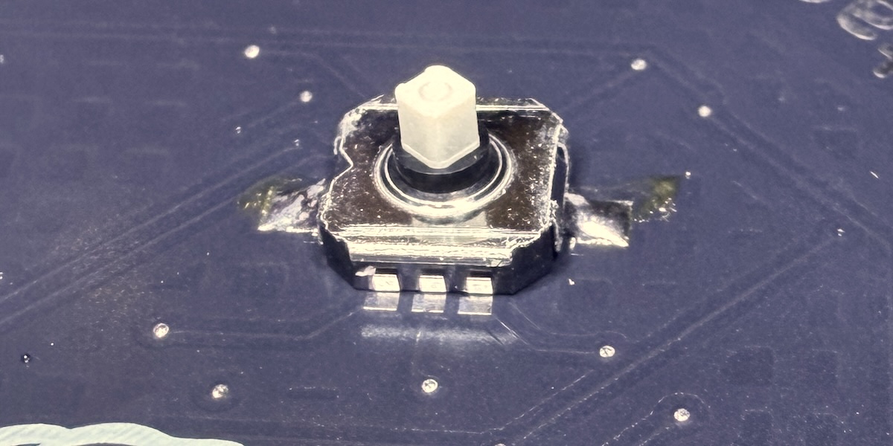
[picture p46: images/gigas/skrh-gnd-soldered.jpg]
five-way switch ground pads soldered


Once the switch is secure, solder the remaining six smaller pads around the edges of the switch.

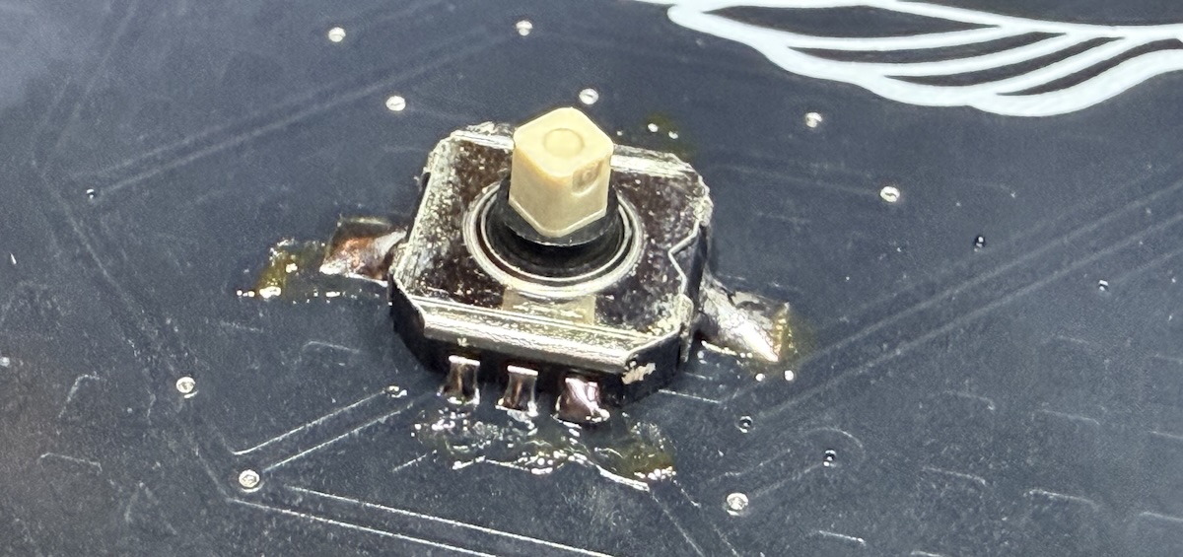
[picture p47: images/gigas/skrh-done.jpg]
five-way switch fully soldered


### Clean the board

Congratulations. You are done soldering all the components.

Use isopropyl alcohol and an old toothbrush to clean the extra flux from the board.

Take a moment and admire your work.

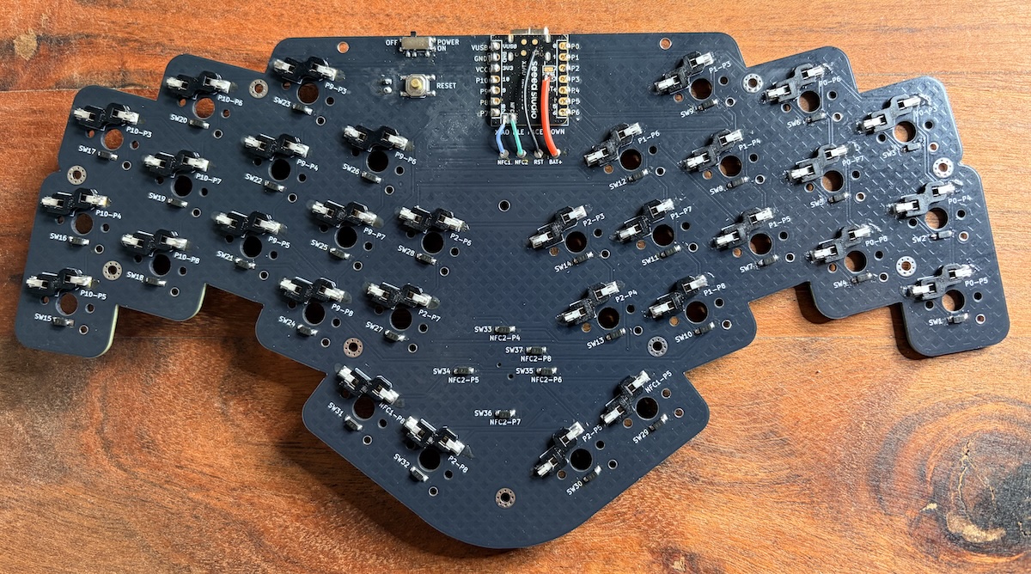
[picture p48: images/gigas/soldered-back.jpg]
soldered board, back view


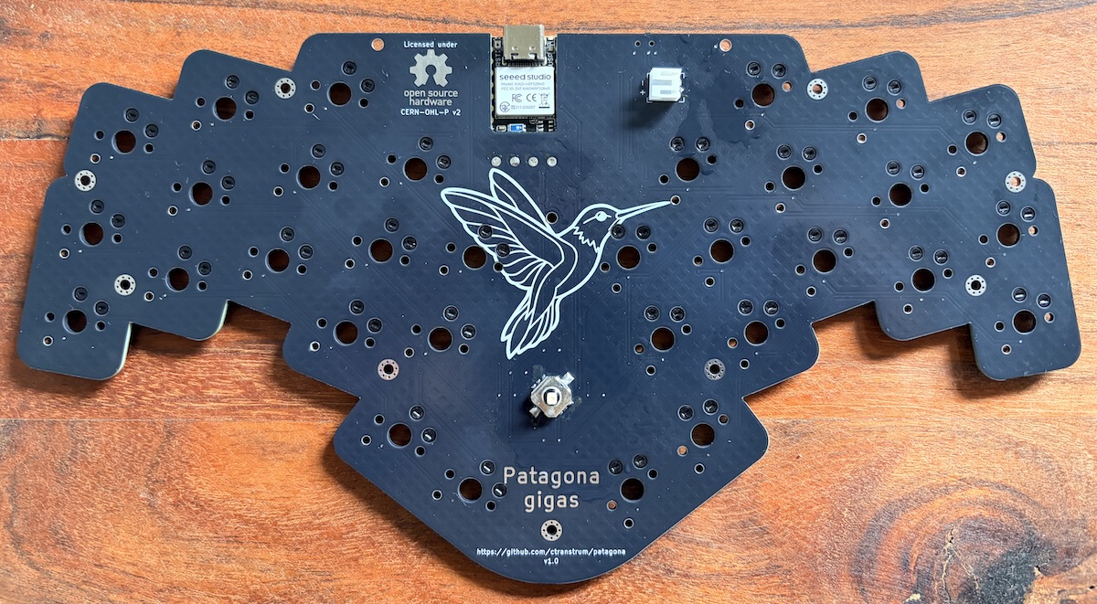
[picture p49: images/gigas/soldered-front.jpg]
soldered board, front view


## Install the case

### Install the heat-set inserts

While you can use your regular soldering tip for installing the heat-set inserts,
it is easier to get better results using a heat-set tip.

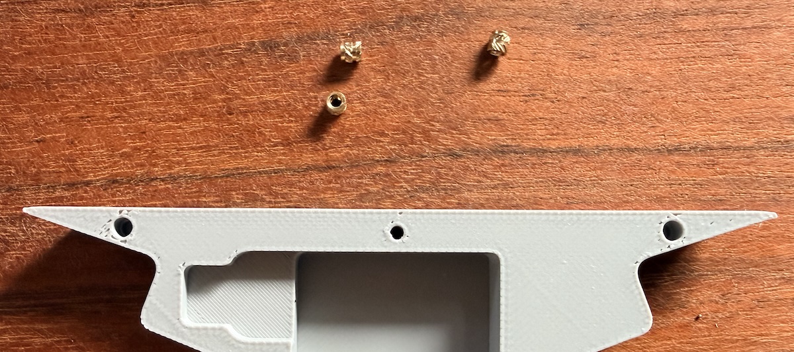
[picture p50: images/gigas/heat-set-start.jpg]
heat-set inserts ready to be installed


Place the heat-set insert above the hole, ensuring that the smaller side is down.
It can be a bit hard to see the different widths of each end,
so feel free to use a magnifier glass if needed.

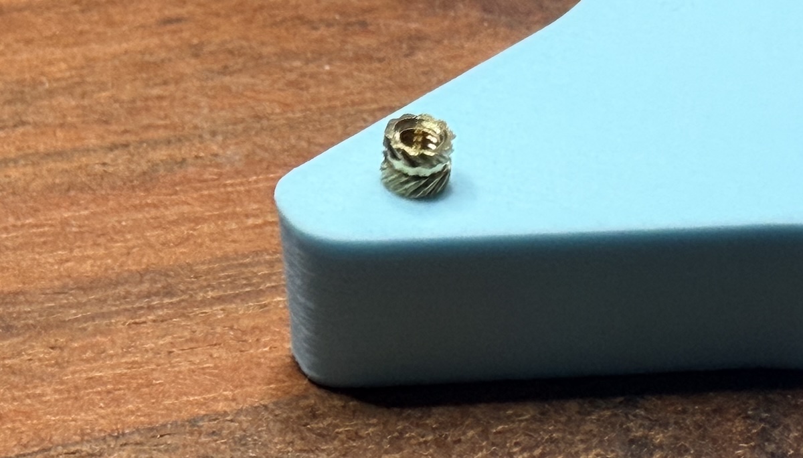
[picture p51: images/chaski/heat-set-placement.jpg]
heat-set orientation placement


Place the heat-set tip into the heat-set insert and apply very gentle pressure
while the tip heats the insert.
The plastic will melt and the insert will glide into place.
Don't push it below the surface of the plastic.

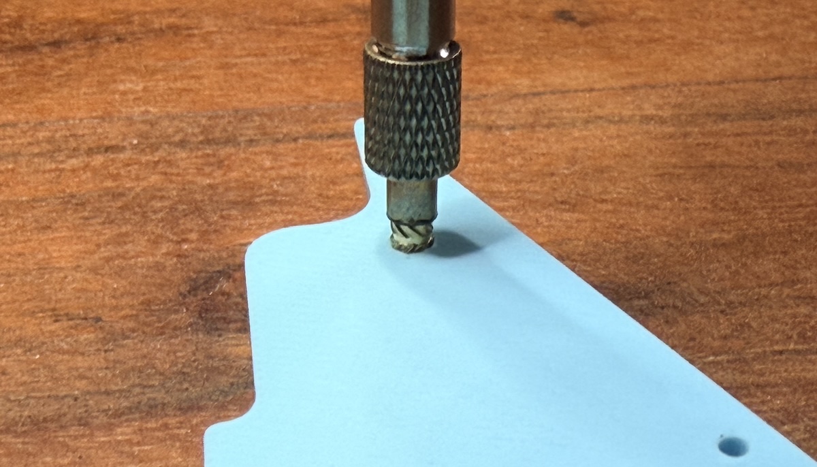
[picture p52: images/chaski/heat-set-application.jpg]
applying the heat-set insert with a heat-set tip


Repeat for the other four heat-set inserts.

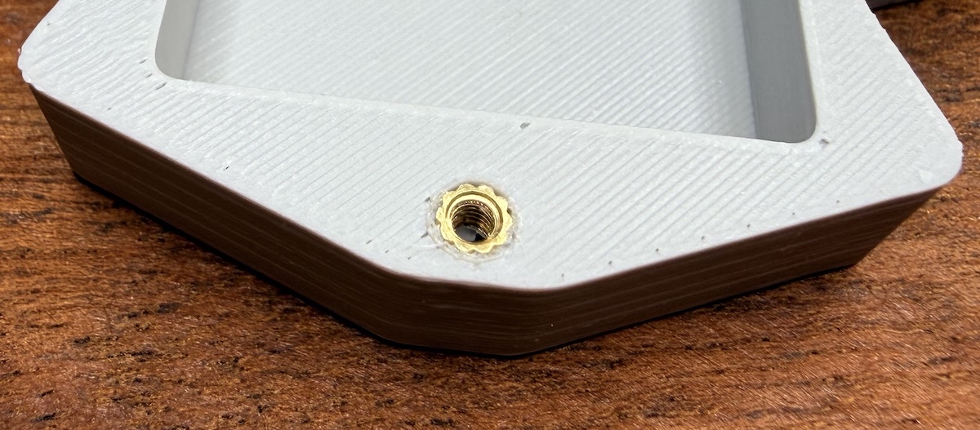
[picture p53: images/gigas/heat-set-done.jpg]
heat-set insert installed flush with battery cover surface


### Top plate

Set the top plate upside down and insert the hex nuts into place in the case.
Note that there are 9 hex nuts used for the standard case,
and only 3 if you are using the rectangle case.

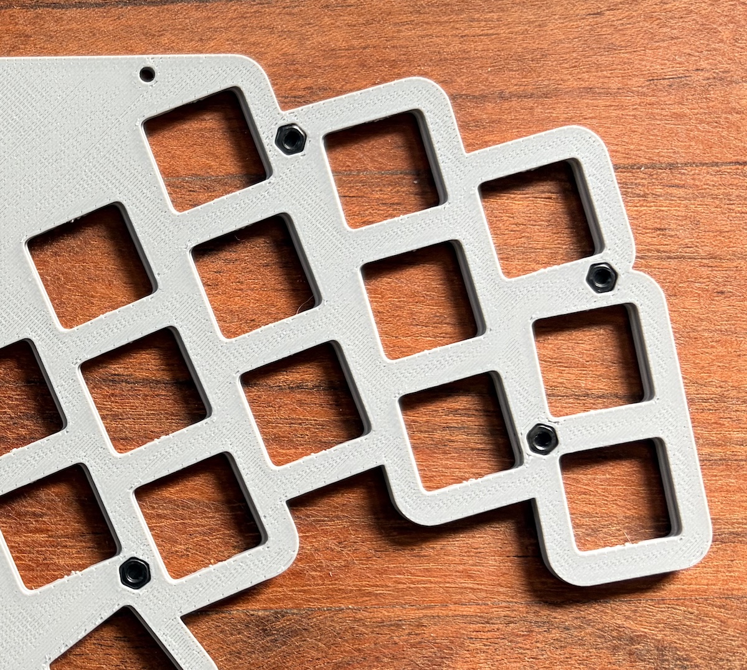
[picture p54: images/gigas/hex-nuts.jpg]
a hex nut inserted into place in the top case


Carefully lift the top plate from the table,
and while holding it upside down so that the hex nuts do not fall,
insert the completed board into place.
The five-way switch and the JST connector will extend below the board,
so it can help to take a couple of books to support each side of the board
in preparation for the next step.

### Bottom case

Place the bottom of the case upside down in place on the exposed bottom of the board.
Insert and secure the 6mm countersunk screws on the left and right sides of the case:
9 screws for the standard case, or 3 if using the rectangle case.

Leave the 3 center screw holes empty for now.

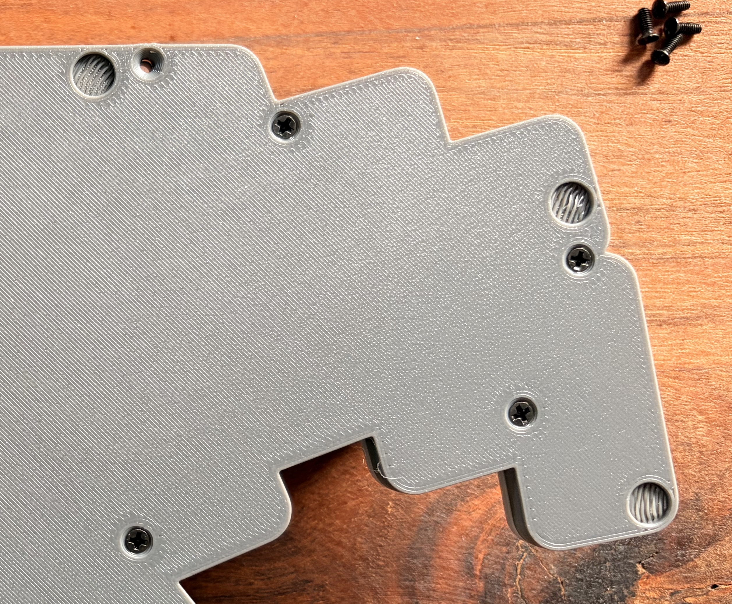
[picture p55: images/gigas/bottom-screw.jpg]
one screw installed in the bottom case


### Battery

Insert the battery JST cable into the JST connector,
carefully observing the polarity of the wires.

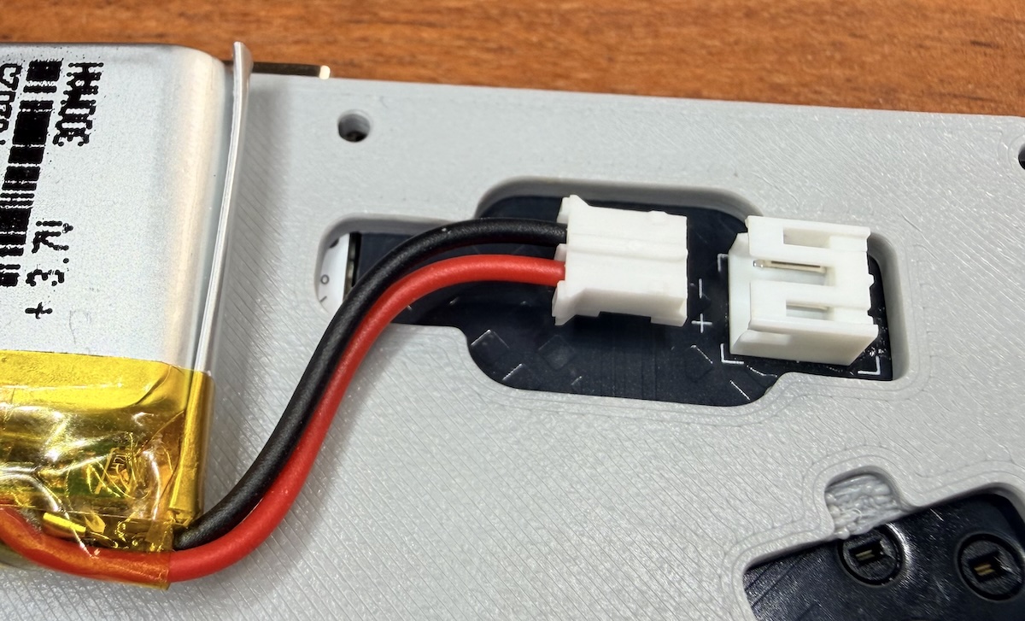
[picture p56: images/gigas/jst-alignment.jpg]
red and black battery wires should align with positive and negative connections on the jst terminal


The red wire should always connect to the + symbol on the board,
and the black wire to the - symbol.
If your battery cable is wired incorrectly, stop now and replace
the wire or buy a different battery.

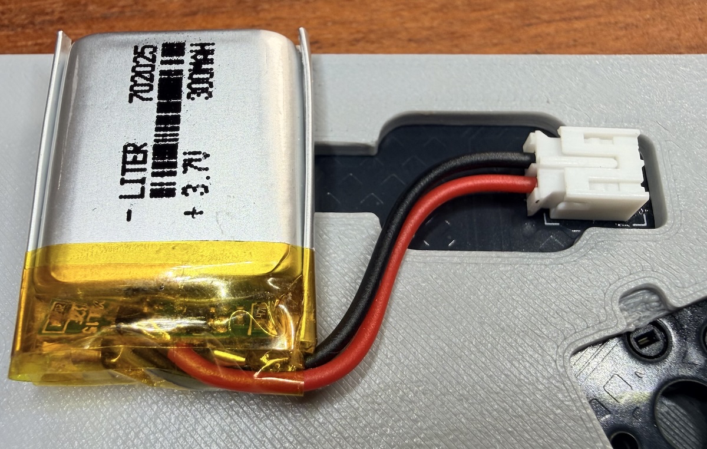
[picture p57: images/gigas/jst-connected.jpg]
battery connected to jst


### LED light guide

Cut a piece of transparent filament about 1cm in length.
Ensure that it can be inserted into the LED light guide hole.
Tolerances on 3D prints are not always great,
so you may need to slightly enlarge the hole,
or if the hole is too loose,
you may need to apply a small amount of glue when installation is complete.

Test the length of the filament by inserting it through the battery cover and
into its place in the top case.
I like to do this before the battery cover is installed so that I can more easily
work with the filament and the holes as needed.

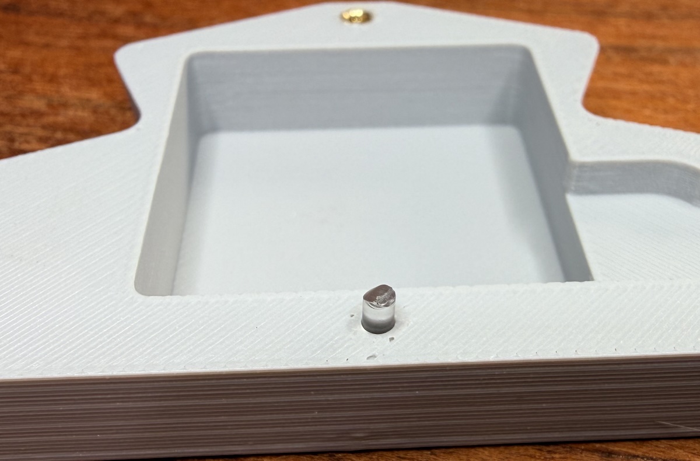
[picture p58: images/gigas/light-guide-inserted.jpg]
filament inserted into place


Ensure that the filament is flush or slightly protrudes maybe half a millimeter when fully inserted.
This filament will bring the light from the LED on the XIAO up to the top surface of the case.

LED light visible through filament light guide

### Battery cover

Finally, arrange the battery and wires in place so that the battery cover can close,
and then insert the three 10mm countersunk screws through the bottom of the case to secure the battery cover.

board installed in top case

### Switches and keycaps

Take care when inserting the switches that the pins of each switch are straight.
Gently place the switch in place, and position it so it is aligned before pushing it
straight down. Do not try to assemble it at an angle. It may take a bit of force to get the
switch fully seated. There should be no gap between the skirt of the switch and the top plate.

installing the switches

Attach the keycaps. Again, try to first align the keycap and then use firm even pressure.

installing the keycaps

### Joystick cap

Press the joystick cap firmly onto the five-way switch until it snaps into place.

joystick cap installed on five-way switch

### Attach the bumpons

Once everything else is installed, flip the keyboard back over and press each bumpon into place
in its designated spot. Your keyboard is now ready for its photoshoot and the installation of firmware.

bumpons installation

## Photoshoot

If you'd like to share your hard work with the rest of the world, take a photo of your new Patagona gigas and
send it to me. My contact information is on my profile. Congratulations on a job well done!

completed gigas build

## Firmware installation

You can grab the default firmware from the [firmware repository][firmware].

To install it, attach the keyboard to the computer by USB,
double-tap the reset button on the bottom of the board,
and then drag the appropriate firmware
to the new device that appears as a thumb drive on the computer's file manager.

drag and drop to install

Note, however, that the "thumb drive" is not actually a real thumb drive, and normal copy and paste operations
do not work as they do on a real thumb drive. Copying the file to the keyboard is really a command to the
microcontroller to install firmware. As soon as the firmware is installed, the keyboard will reboot and start
running the new firmware. This will make the "thumb drive" immediately disconnect from the computer, which
is often seen as an error by the operating system.

ignore read/write error

But you are free to ignore that error and just start using the keyboard. Just don't try to copy anything that's
not a firmware to the keyboard, and you should be fine.

## Problems?

For more information about using [ZMK][zmk], including how to use [ZMK Studio][zmkstudio],
or how to configure your own [zmk repo][zmkrepo], please refer to the [ZMK docs][zmkdocs].

If you still have the default keymap installed and want to update the layout with [ZMK Studio][zmkstudio],
the "ZMK Studio unlock" key combination is accessed
by simultaneously pressing the keys that are by default mapped to Esc and Backspace.
Note that as of the time of this writing, you will need to be using Chrome or Edge to get it to work.

If a single key isn't working,
the first thing to look at is that the switch has been installed properly,
and the pins aren't bent.
The second most likely cause of a single key not working is an improperly installed diode.
Find the diode closest to that key and ensure it is installed in the correct orientation
and that both legs are well attached to the PCB.

If you need to troubleshoot the soldering by shorting MCU pins to test the firmware is working,
the pins used for each switch are printed on the PCB next to the switch.
An example label would be something like `P0-P5`,
which means that the switch connects P0 to P5.
To test that switch, simply short those two pins together.

If you need to correct any soldering,
access to the bottom of the PCB involves removing all 12 screws from the bottom of the case.
You do not necessarily need to remove all the switches.
However, if you are doing extensive re-soldering work,
it may be a good idea to fully remove the PCB from the case.
This will prevent the heat from the soldering iron from deforming the case.

One unexpected feature of the XIAO BLE microcontroller is that the power switch must be "ON"
in order for the battery to charge while plugged into a USB-C cable.
An easy way to remember: sliding the power switch toward the USB port turns the keyboard on,
while sliding it away from the USB port turns it off.

[battery]: https://ydlbattery.com/products/3-7v-400mah-802525-lithium-polymer-ion-battery
[bumpons]: https://www.amazon.com/HAWORTHS-Bumpers-Self-adhesive-Bumpons-Diameter/dp/B07R17T68B
[case]: https://github.com/ctranstrum/patagona/tree/main/cases/gigas#readme
[gigas-gerber]: pcb/gigas.zip
[chockeycaps]: https://lowprokb.ca/collections/keycaps/products/ldsa-low-profile-blank-keycaps
[chocv1]: https://lowprokb.ca/collections/switches/products/ambients-silent-choc-switches
[chocv2]: https://www.lofree.co/products/void-low-profile-pom-switches
[filament]: https://gizmodorks.com/nylon-filament-200-g-spool/
[firmware]: https://github.com/ctranstrum/patagona-zmk
[fiveswitch]: https://www.mouser.com/en/ProductDetail/Alps-Alpine/SKRHADE010?qs=seHrhfPpLDxlAi0Di%252BJD5Q%3D%3D
[heatset]: https://www.partsbuilt.com/m2-heat-set-thread-insert-3mm-wide-3mm-long-4-pack/
[heatsettool]: https://pine64.com/product/pinecil-threaded-insert-tips-set-and-adapter/
[hexnuts]: https://monsterbolts.com/products/nuts-din934-a2
[how-to-solder]: https://www.google.com/search?q=youtube+how+to+solder
[jlc3dp]: https://jlc3dp.com/
[jlcpcb]: https://jlcpcb.com/
[jst]: https://typeractive.xyz/products/battery-jack
[kester]: https://typeractive.xyz/products/kester-solder-wire-tube
[mxkeycaps]: https://nuphy.com/collections/keycaps?compatibility=low-profile-keys
[pinecil]: https://typeractive.xyz/products/pinecil
[power]: https://typeractive.xyz/products/power-switch
[pts526]: https://www.littelfuse.com/assetdocs/littelfuse-ck-tactile-pts526-series-datasheet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
[reset]: https://www.aliexpress.us/item/3256806760201032.html
[screws6mm]: https://monsterbolts.com/products/mach-phil-flat-a2-m2?variant=21222571802707
[screws10mm]: https://monsterbolts.com/products/mach-phil-flat-a2-m2?variant=21222572064851
[sockets]: https://typeractive.xyz/products/hotswap-sockets?variant=45742200324327
[sod123]: https://typeractive.xyz/products/smd-diodes
[soldering101]: https://www.google.com/search?q=youtube+soldering+101
[splitkb-build-guide]: https://docs.splitkb.com/product-guides/aurora-series/build-guide
[ts18]: https://www.sameskydevices.com/product/resource/ts18.pdf
[wire]: https://www.walmart.com/ip/26-Gauge-PVC-Hookup-Wire-1-5m-5ft-26AWG-Flexible-Electrical-Wire-Tinned-Copper-Stranded-6-Color-1-5mm/5487030958
[xiao]: https://www.seeedstudio.com/Seeed-XIAO-BLE-nRF52840-p-5201.html
[zmk]: https://zmk.dev
[zmkdocs]: https://zmk.dev/docs
[zmkrepo]: https://zmk.dev/docs/user-setup
[zmkstudio]: https://zmk.studio/

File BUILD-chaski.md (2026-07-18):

# Patagona chaski Build Guide

If this is your first time building a custom keyboard,
you should do two things before attempting this build.

- watch a few [soldering][how-to-solder] [tutorials][soldering101]
- read through a detailed build guide like
  the one for the [splitkb.com Aurora Series][splitkb-build-guide]

The remainder of this build guide will assume a basic familiarity with the process
and will only hit upon specific items that may be different or important to note while
building the Patagona chaski.

## Bill of materials

| Qty | Description |
| --- | --- |
| 1 | Chaski PCB (can be printed by uploading the [zip file][chaski-gerber] to [JLC][jlcpcb]) |
| 3 | [3D printed cases][case] |
| 1 | [XIAO BLE][xiao] |
| 1 | [SMD 5x5x3 tactile switch][reset] for the reset button (similar to [this][pts526] or [this][ts18]) |
| 1 | [Alps SSSS811101 SPDT slide switch][power] for the battery on/off |
| 1 | [3.7v 400mAh 802525 LiPo battery][battery] or smaller (max internal space: 8x28x29mm) |
| 1 | [JST PH-2 battery jack][jst] |
| 40-42  | SOD-123 [1N4148W SMD diodes][sod123] |
| 40-42  | Kailh [choc hot swap sockets][sockets] |
| 40-42  | [Choc v1][chocv1] or [v2 switches][chocv2] of your choice |
| 40-42  | [Low profile choc v1][chockeycaps] or [v2 keycaps][mxkeycaps] of your choice |
| 4 (2)  | [M2 x 6mm countersunk screws][screws6mm] |
| 4 (2)  | [M2 hex nuts][hexnuts] |
| 5 | [M2 x 10mm countersunk screws][screws10mm] |
| 5 | [M2 heat-set inserts 3mm x 3mm][heatset] |
| 10 (8) | [6mm x 1.5mm bumpons][bumpons] |
| ~1cm | [1.75mm transparent 3D printer filament][filament] for the "fiber optic" led light guide |
| 4 | short (1-2cm) pieces of [26 gauge electrical wire][wire] |

**Note**: When assembling a chaski build in a rectangle case, you will use fewer 6mm screws, hex nuts, and bumpons.
The quantities for the rectangle case are given in parentheses.

## Useful equipment

You will need:

- a [soldering iron][pinecil]
- some [good quality solder][kester]
- precision tweezers
- wire cutter / stripper

You should ideally have access to:

- a [heat-set insert tool][heatsettool]
- a decent hands-free magnifying glass
- isopropyl alcohol and an old toothbrush

## Getting the PCB

The PCB can be easily ordered from a circuit board manufacturer with an online store.
I used [JLC][jlcpcb] because--at least at the time of my order--their prices are unbeatable.

To order, you can simply upload the [gerber zip file][chaski-gerber] to their website,
accept all of the defaults, and wait a week or two for the boards to arrive.

However, the minimum order at JLC is 5 copies, so you'll likely end up
with 4 extra PCBs. I don't really have any advice for what to do with
the extras, but you maybe could give one to a friend!

A couple items that you may want to customize:

- the color of the board; I printed mine in black
- HASL can be lead-free if you are also using lead-free solder, or you can splurge for ENIG, but it's definitely not required

chaski pcb render

## Getting the case

If you have access to a 3D printer, the [case][case] is very easy to print yourself.

If you don't have your own printer, no worries.
You will probably want to send in your print order around the same time you order the PCB.
I've used [JLC][jlc3dp] in the past with good results.

Just remember that you should print the battery cover
in nylon or PLA rather than resin,
though all other parts of the case can be printed in resin.
The reason for this is that the design calls for heat-set inserts
to be melted into that piece, and resin doesn't work for that.

## General soldering order

Although you can work in any order you prefer,
I like to start with the smaller components, then move to the larger,
and finish with bulky items that go on the top of the board.

So, the order I install:

### Installed on the bottom of the board

- diodes
- hotswap sockets
- power switch
- reset switch
- xiao
- reset and battery wire connections to xiao

### Bulky item, assembled on the top of the board, but soldered on the bottom

- jst

## Step-by-step instructions

Let's get started, shall we?

### Solder the diodes

diodes and PCB ready to begin soldering

Diodes are directional components, and must be soldered in the correct orientation.

To determine the orientation, look for a line printed on one edge of the diode.
You may need to use a magnifier glass and adjust the angle of light hitting the diode
in order to see it clearly.
Once you find the line on the diode, you can align it with the silk-screened line on the PCB,
and then solder with both lines on the same side.

All diodes are installed in roughly the same direction on the board, with the line on the right.

To easily install a diode, first place a small amount of solder onto one of the diode pads.

diode with one pad soldered, ready to place

Then grab the diode with tweezers and orient it correctly.
Reheat the soldered pad, then slide the diode into place.
Remove the heat, and when the solder cools, release the diode.

diode with both legs soldered in place

With one leg installed, you can apply solder to the other leg.

Complete all diodes, being sure to double-check that they are all oriented
correctly and both legs are soldered before moving to the next step.

### Solder the hotswap sockets

sockets ready to be soldered to the PCB

While hotswap sockets will work the same way electrically no matter which way they are installed,
the tolerances of the case are such that you should take care to install these
according to the markings on the PCB as well.

In the following picture, the blue box on SW22 shows the silkscreen line before
a hotswap socket is installed, the green box on SW19 shows a hotswap socket in the
correct orientation where the silkscreen line is mostly hidden by the straight lines of
the bottom edge of the socket, and the red box on SW23 shows an incorrectly oriented
hotswap socket, where the silkscreen line is clearly visible poking out around the
angled edges of the socket.

three sockets showing correct and incorrect orientation

Place the hotswap socket into the PCB holes,
being sure that the silkscreen on the PCB matches the orientation of the socket,
then apply solder to one of the legs.

This will take a lot more solder than the diode did, but be careful not to get carried away.
The solder should not overflow the pad or rise above the socket.

hotswap socket with first leg soldered

Once done, use tweezers to hold the socket in place until the solder cools.

Flip the board around and solder the other pad.

hotswap socket with both legs soldered

Solder all the sockets on the board.

### Solder the power switch

power switch ready to be soldered

To solder the power switch, first apply a bit of solder to one of the pads.

Holding the power switch in place with tweezers, reheat the soldered pad
and align the power switch. Remove the heat, and release the power switch
only after the solder has cooled.

Once satisfied with the placement, solder each of the other pads, being very careful
not to allow the solder to connect neighboring pads.

power switch fully soldered

### Solder the reset switch

reset switch ready to be soldered

The reset switch follows the same process,
though it can require a little more attention to align it correctly.

Apply solder to one pad,
use tweezers to slide the reset switch into place while reheating the solder,
and remove the heat when you are satisfied with the alignment.

first pad ready to receive the reset switch

Complete the remaining pads.

reset switch fully soldered

### Solder the xiao

PCB elevated for installation of the XIAO

The xiao is installed upside down,
with the components on top of the xiao extending
into and beyond the space of the PCB.

Because of this, the xiao will need a little space under it,
since it is thicker than the PCB.
I like to stack another board below it to provide that space,
but any method of elevating the board will work.

Begin by placing a little solder on one of the corner pads.
Put the xiao in place, reheat the soldered pad,
and ensure the correct placement of the xiao before removing the heat.

xiao with one corner pad soldered

Once the solder cools and you are satisfied that the xiao is in the correct place,
solder the opposite corner. It can be a little tricky to get heat on both the
pad of the PCB as well as the xiao's pad, so take your time, use plenty of heat,
and wait until you see the solder moving below the xiao and filling a bit of the
through-hole.

xiao fully soldered to PCB

Repeat this process until all the pads of the xiao are soldered well to the board.
I also usually re-solder the first pad I did,
since it likely has the least amount of solder on it compared to all the others.

### Solder the xiao connections

Begin by cutting a short piece of wire a little bit longer than needed to connect the pad to the through-hole.

For the power connection, this connects the BAT+ hole on the PCB with the BAT+ pad on the back of the xiao.

BAT+ wire ready to connect xiao to PCB

Trim about 1.5mm of shielding off each end of the wire, and then solder the wire.
I like to start with the end on the xiao's pad, and once that is in place,
stick the other end into the through hole and solder there as well.

The reset wire connects the RST hole on the PCB to the unlabeled reset pad on the back of the xiao.

Even though it's unlabeled, it's not difficult to find.
There are four circular pads near the USB port at the top of the xiao.

Location of the RST pad on the XIAO BLE:

location of RST pad on the back of the XIAO BLE

Install it using the same method as the BAT+ wire.

RST wire connecting xiao to PCB

The final two wires connect the NFC1 and NFC2 holes on the PCB to the NFC pads on the back of the xiao.
The xiao has two NFC pads near each other, though only one of them is labeled.
Install these wires so that they run parallel to each other:
NFC2 on the PCB connects to the right NFC pad on the xiao,
and NFC1 on the PCB connects to the left NFC pad on the xiao.
Install NFC2 first, then NFC1.

NFC2 wire cut and ready to install

NFC2 installed, NFC1 wire cut and ready to install

all four wires complete

### Solder the JST connector

Unlike all components so far,
the JST connector needs to be inserted into place from the opposite side of the board.

jst ready to be inserted on front of PCB

Once in place, secure it temporarily with a little tape
while you solder the legs on the other side of the board.

Remove the tape when done.

jst legs soldered on back of PCB

### Clean the board

Congratulations. You are done soldering all the components.

Use isopropyl alcohol and an old toothbrush to clean the extra flux from the board.

Take a moment and admire your work.

soldered board, back view

soldered board, front view

## Install the case

### Install the heat-set inserts

While you can use your regular soldering tip for installing the heat-set inserts,
it is easier to get better results using a heat-set tip.

heat-set inserts ready to be installed

Place the heat-set insert above the hole, ensuring that the smaller side is down.
It can be a bit hard to see the different widths of each end,
so feel free to use a magnifier glass if needed.

heat-set orientation placement

Place the heat-set tip into the heat-set insert and apply very gentle pressure
while the tip heats the insert.
The plastic will melt and the insert will glide into place.
Don't push it below the surface of the plastic.

applying the heat-set insert with a heat-set tip

Repeat for the other four heat-set inserts.

heat-set insert installed flush with battery cover surface

### Top plate

Set the top plate upside down and insert the hex nuts into place in the case.
Note that there are 4 hex nuts used for the standard case,
and only 2 if you are using the rectangle case.

a hex nut inserted into place in the top case

Carefully lift the top plate from the table,
and while holding it upside down so that the hex nuts do not fall,
insert the completed board into place.
The JST connector will extend below the board,
so it can help to take a couple of books to support each side of the board
in preparation for the next step.

### Bottom case

Place the bottom of the case upside down in place on the exposed bottom of the board.
Insert and secure the 6mm countersunk screws on the left and right sides of the case:
4 screws for the standard case, or 2 if using the rectangle case.

Leave the 5 center screw holes empty for now.

one screw installed in the bottom case

### Battery

Insert the battery JST cable into the JST connector,
carefully observing the polarity of the wires.

red and black battery wires should align with positive and negative connections on the jst terminal

The red wire should always connect to the + symbol on the board,
and the black wire to the - symbol.
If your battery cable is wired incorrectly, stop now and replace
the wire or buy a different battery.

battery connected to jst

### LED light guide

Cut a piece of transparent filament about 1cm in length.
Ensure that it can be inserted into the LED light guide hole.
Tolerances on 3D prints are not always great,
so you may need to slightly enlarge the hole,
or if the hole is too loose,
you may need to apply a small amount of glue when installation is complete.

filament cut to approximate size

Test the length of the filament by inserting it through the battery cover and
into its place in the top case.
I like to do this before the battery cover is installed so that I can more easily
work with the filament and the holes as needed.

filament inserted into place

Ensure that the filament is flush or slightly protrudes maybe half a millimeter when fully inserted.
This filament will bring the light from the LED on the XIAO up to the top surface of the case.

filament flush with top of case

### Battery cover

Finally, arrange the battery and wires in place so that the battery cover can close,
and then insert the five 10mm countersunk screws through the bottom of the case to secure the battery cover.

installing the 10mm screws

### Switches and keycaps

Take care when inserting the switches that the pins of each switch are straight.
Gently place the switch in place, and position it so it is aligned before pushing it
straight down. Do not try to assemble it at an angle. It may take a bit of force to get the
switch fully seated. There should be no gap between the skirt of the switch and the top plate.

installing the switches

Attach the keycaps. Again, try to first align the keycap and then use firm even pressure.

installing the keycaps

### Attach the bumpons

Once everything else is installed, flip the keyboard back over and press each bumpon into place
in its designated spot. Your keyboard is now ready for its photoshoot and the installation of firmware.

bumpons installation

## Photoshoot

If you'd like to share your hard work with the rest of the world, take a photo of your new Patagona chaski and
send it to me. My contact information is on my profile. Congratulations on a job well done!

completed chaski build

## Firmware installation

You can grab the default firmware from the [firmware repository][firmware].

To install it, attach the keyboard to the computer by USB,
double-tap the reset button on the bottom of the board,
and then drag the appropriate firmware
to the new device that appears as a thumb drive on the computer's file manager.

drag and drop to install

Note, however, that the "thumb drive" is not actually a real thumb drive, and normal copy and paste operations
do not work as they do on a real thumb drive. Copying the file to the keyboard is really a command to the
microcontroller to install firmware. As soon as the firmware is installed, the keyboard will reboot and start
running the new firmware. This will make the "thumb drive" immediately disconnect from the computer, which
is often seen as an error by the operating system.

ignore read/write error

But you are free to ignore that error and just start using the keyboard. Just don't try to copy anything that's
not a firmware to the keyboard, and you should be fine.

## Problems?

For more information about using [ZMK][zmk], including how to use [ZMK Studio][zmkstudio],
or how to configure your own [zmk repo][zmkrepo], please refer to the [ZMK docs][zmkdocs].

If you still have the default keymap installed and want to update the layout with [ZMK Studio][zmkstudio],
the "ZMK Studio unlock" key combination is accessed
by simultaneously pressing the keys that are by default mapped to Esc and Backspace.
Note that as of the time of this writing, you will need to be using Chrome or Edge to get it to work.

If a single key isn't working,
the first thing to look at is that the switch has been installed properly,
and the pins aren't bent.
The second most likely cause of a single key not working is an improperly installed diode.
Find the diode closest to that key and ensure it is installed in the correct orientation
and that both legs are well attached to the PCB.

If you need to troubleshoot the soldering by shorting MCU pins to test the firmware is working,
the pins used for each switch are printed on the PCB next to the switch.
An example label would be something like `P0-P5`,
which means that the switch connects P0 to P5.
To test that switch, simply short those two pins together.

If you need to correct any soldering,
access to the bottom of the PCB involves removing all 9 screws from the bottom of the case.
You do not necessarily need to remove all the switches.
However, if you are doing extensive re-soldering work,
it may be a good idea to fully remove the PCB from the case.
This will prevent the heat from the soldering iron from deforming the case.

One unexpected feature of the XIAO BLE microcontroller is that the power switch must be "ON"
in order for the battery to charge while plugged into a USB-C cable.
An easy way to remember: sliding the power switch toward the USB port turns the keyboard on,
while sliding it away from the USB port turns it off.

[battery]: https://ydlbattery.com/products/3-7v-400mah-802525-lithium-polymer-ion-battery
[bumpons]: https://www.amazon.com/HAWORTHS-Bumpers-Self-adhesive-Bumpons-Diameter/dp/B07R17T68B
[case]: https://github.com/ctranstrum/patagona/tree/main/cases/chaski#readme
[chaski-gerber]: pcb/chaski.zip
[chockeycaps]: https://lowprokb.ca/collections/keycaps/products/ldsa-low-profile-blank-keycaps
[chocv1]: https://lowprokb.ca/collections/switches/products/ambients-silent-choc-switches
[chocv2]: https://www.lofree.co/products/void-low-profile-pom-switches
[filament]: https://gizmodorks.com/nylon-filament-200-g-spool/
[firmware]: https://github.com/ctranstrum/patagona-zmk
[heatset]: https://www.partsbuilt.com/m2-heat-set-thread-insert-3mm-wide-3mm-long-4-pack/
[heatsettool]: https://pine64.com/product/pinecil-threaded-insert-tips-set-and-adapter/
[hexnuts]: https://monsterbolts.com/products/nuts-din934-a2
[how-to-solder]: https://www.google.com/search?q=youtube+how+to+solder
[jlc3dp]: https://jlc3dp.com/
[jlcpcb]: https://jlcpcb.com/
[jst]: https://typeractive.xyz/products/battery-jack
[kester]: https://typeractive.xyz/products/kester-solder-wire-tube
[mxkeycaps]: https://nuphy.com/collections/keycaps?compatibility=low-profile-keys
[pinecil]: https://typeractive.xyz/products/pinecil
[power]: https://typeractive.xyz/products/power-switch
[pts526]: https://www.littelfuse.com/assetdocs/littelfuse-ck-tactile-pts526-series-datasheet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
[reset]: https://www.aliexpress.us/item/3256806760201032.html
[screws6mm]: https://monsterbolts.com/products/mach-phil-flat-a2-m2?variant=21222571802707
[screws10mm]: https://monsterbolts.com/products/mach-phil-flat-a2-m2?variant=21222572064851
[sockets]: https://typeractive.xyz/products/hotswap-sockets?variant=45742200324327
[sod123]: https://typeractive.xyz/products/smd-diodes
[soldering101]: https://www.google.com/search?q=youtube+soldering+101
[splitkb-build-guide]: https://docs.splitkb.com/product-guides/aurora-series/build-guide
[ts18]: https://www.sameskydevices.com/product/resource/ts18.pdf
[wire]: https://www.walmart.com/ip/26-Gauge-PVC-Hookup-Wire-1-5m-5ft-26AWG-Flexible-Electrical-Wire-Tinned-Copper-Stranded-6-Color-1-5mm/5487030958
[xiao]: https://www.seeedstudio.com/Seeed-XIAO-BLE-nRF52840-p-5201.html
[zmk]: https://zmk.dev
[zmkdocs]: https://zmk.dev/docs
[zmkrepo]: https://zmk.dev/docs/user-setup
[zmkstudio]: https://zmk.studio/

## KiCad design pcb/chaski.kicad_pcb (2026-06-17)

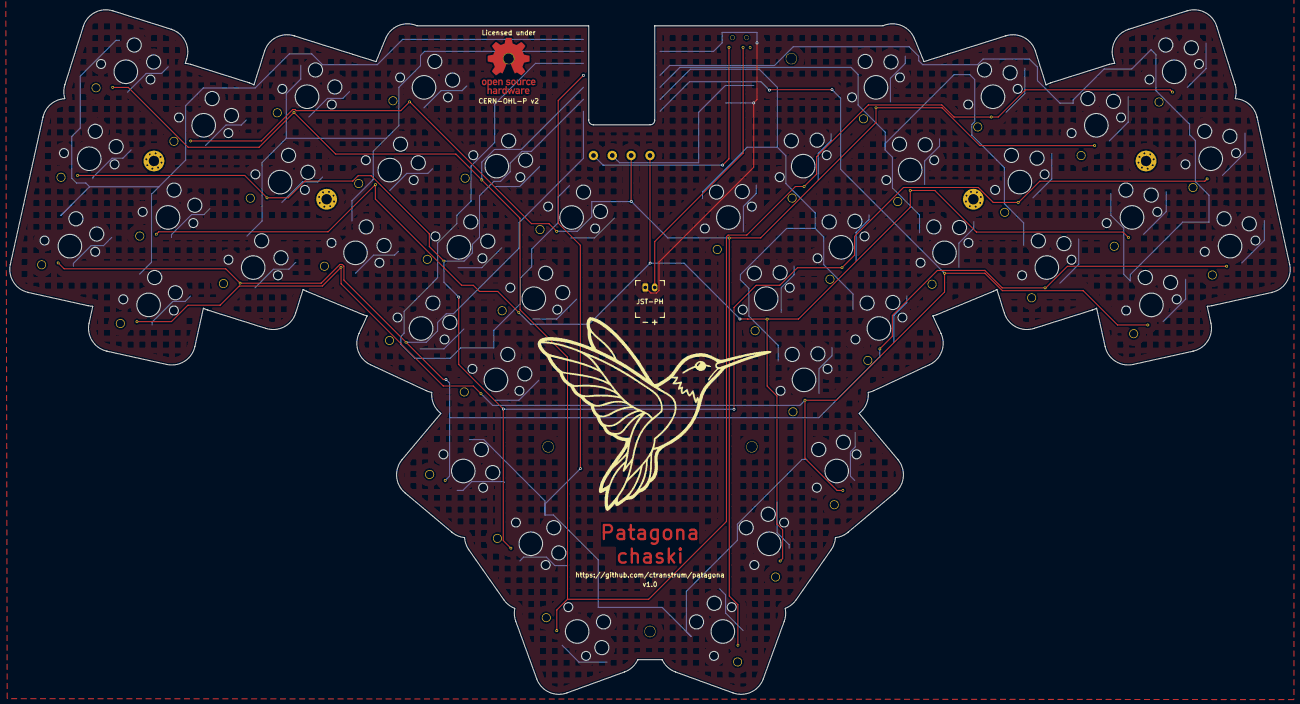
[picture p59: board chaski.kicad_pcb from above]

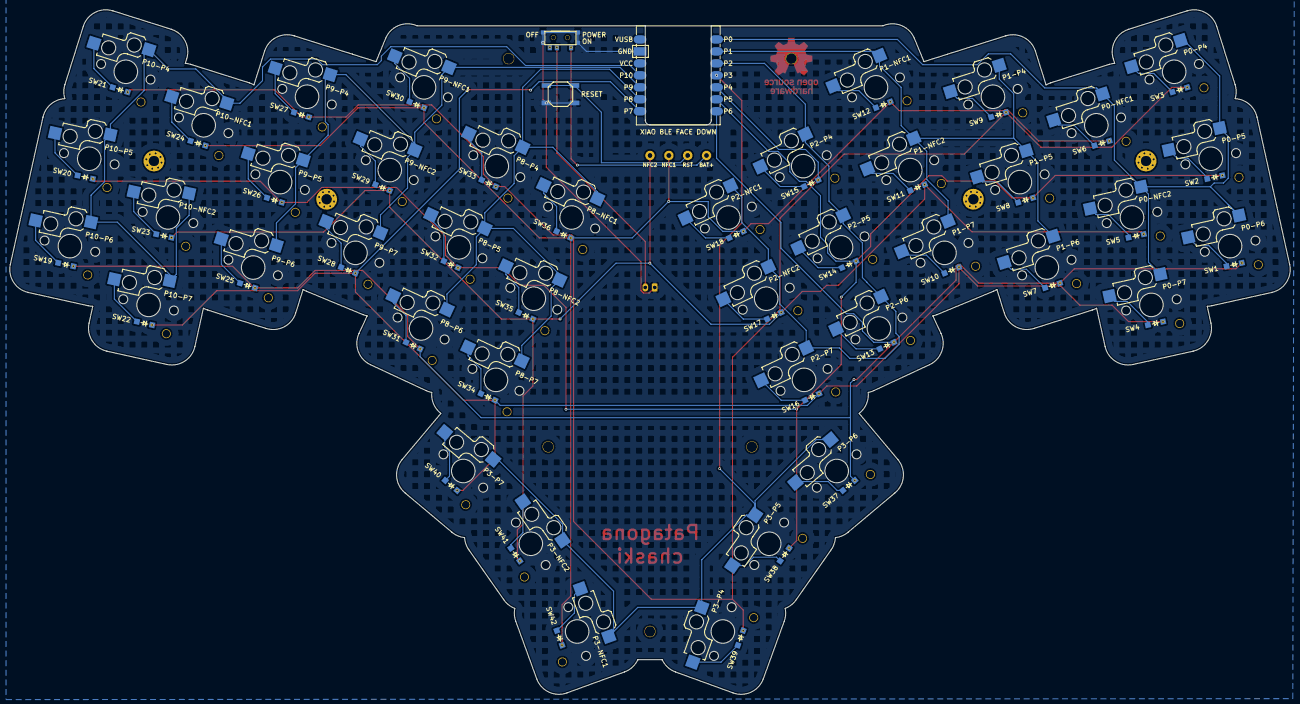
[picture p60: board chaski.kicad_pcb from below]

Board: 2 copper layers, 271.7 x 145.2 mm, 93 parts (85 on the bottom side), 59 nets.

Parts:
JST1: battery_connector_jst_ph_2
MCU1: xiao-ble
PAD1, PAD2, PAD3, PAD4: SMDPad
PG**: p-gigas
S1, S2, S3, S4, S5, S6, S7, S8, S9, S10, S11, S12, S13, S14, S15, S16, S17, S18, S19, S20, S21, S22, S23, S24, S25, S26, S27, S28, S29, S30, S31, S32, S33, S34, S35, S36, S37, S38, S39, S40, S41, S42: switch_choc_v1_v2
SW1, SW2, SW3, SW4, SW5, SW6, SW7, SW8, SW9, SW10, SW11, SW12, SW13, SW14, SW15, SW16, SW17, SW18, SW19, SW20, SW21, SW22, SW23, SW24, SW25, SW26, SW27, SW28, SW29, SW30, SW31, SW32, SW33, SW34, SW35, SW36, SW37, SW38, SW39, SW40, SW41, SW42: ComboDiode
SW43: pts526
T1: SPDT_C128955

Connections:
BAT+: PAD1.1, T1.1
GND: JST1.1, MCU1.13, SW43.1
NFC1: PAD3.1, SW6.1, SW12.1, SW18.1, SW24.1, SW30.1, SW36.1, SW42.1
NFC2: PAD4.1, SW5.1, SW11.1, SW17.1, SW23.1, SW29.1, SW35.1, SW41.1
P0: MCU1.1, S1.1, S2.1, S3.1, S4.1, S5.1, S6.1
P1: MCU1.2, S7.1, S8.1, S9.1, S10.1, S11.1, S12.1
P2: MCU1.3, S13.1, S14.1, S15.1, S16.1, S17.1, S18.1
P3: MCU1.4, S37.1, S38.1, S39.1, S40.1, S41.1, S42.1
P4: MCU1.5, SW3.1, SW9.1, SW15.1, SW21.1, SW27.1, SW33.1, SW39.1
P5: MCU1.6, SW2.1, SW8.1, SW14.1, SW20.1, SW26.1, SW32.1, SW38.1
P6: MCU1.7, SW1.1, SW7.1, SW13.1, SW19.1, SW25.1, SW31.1, SW37.1
P7: MCU1.8, SW4.1, SW10.1, SW16.1, SW22.1, SW28.1, SW34.1, SW40.1
P8: MCU1.9, S31.1, S32.1, S33.1, S34.1, S35.1, S36.1
P9: MCU1.10, S25.1, S26.1, S27.1, S28.1, S29.1, S30.1
P10: MCU1.11, S19.1, S20.1, S21.1, S22.1, S23.1, S24.1
RAW: JST1.2, T1.2
RST: PAD2.1, SW43.2
index_bottom: S13.2, SW13.2
index_home: S14.2, SW14.2
index_top: S15.2, SW15.2
inner_bottom: S16.2, SW16.2
inner_home: S17.2, SW17.2
inner_top: S18.2, SW18.2
middle_bottom: S10.2, SW10.2
middle_home: S11.2, SW11.2
middle_top: S12.2, SW12.2
mirror_index_bottom: S31.2, SW31.2
mirror_index_home: S32.2, SW32.2
mirror_index_top: S33.2, SW33.2
mirror_inner_bottom: S34.2, SW34.2
mirror_inner_home: S35.2, SW35.2
mirror_inner_top: S36.2, SW36.2
mirror_middle_bottom: S28.2, SW28.2
mirror_middle_home: S29.2, SW29.2
mirror_middle_top: S30.2, SW30.2
mirror_outer_bottom: S19.2, SW19.2
mirror_outer_home: S20.2, SW20.2
mirror_outer_top: S21.2, SW21.2
mirror_pinky_bottom: S22.2, SW22.2
mirror_pinky_home: S23.2, SW23.2
mirror_pinky_top: S24.2, SW24.2
mirror_primary_spot: S41.2, SW41.2
mirror_reachy_spot: S42.2, SW42.2
mirror_ring_bottom: S25.2, SW25.2
mirror_ring_home: S26.2, SW26.2
mirror_ring_top: S27.2, SW27.2
mirror_secondary_spot: S40.2, SW40.2
outer_bottom: S1.2, SW1.2
outer_home: S2.2, SW2.2
outer_top: S3.2, SW3.2
pinky_bottom: S4.2, SW4.2
pinky_home: S5.2, SW5.2
pinky_top: S6.2, SW6.2
primary_spot: S38.2, SW38.2
reachy_spot: S39.2, SW39.2
ring_bottom: S7.2, SW7.2
ring_home: S8.2, SW8.2
ring_top: S9.2, SW9.2
secondary_spot: S37.2, SW37.2

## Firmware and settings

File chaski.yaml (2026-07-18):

meta:
  keyboard: &keyboard_name Patagona chaski
  genus: &keyboard_genus Patagona
  species: &keyboard_species chaski
  author: chad@transtrum.net
  version: &version v1.0
  repository: &repo https://github.com/ctranstrum/patagona
  license: &license CERN-OHL-P v2

  # Depending on where you are ordering from, uncomment or edit one of these:
  # order_num_template: &order_text JLCJLCJLCJLC # for ordering from JLCpcb.com
  # order_num_template: &order_text WayWayWay    # for ordering from PCBway.com
  order_num_template: &order_text "" # remove the order number text completely

units:
  dx: u
  dy: u

  hdx: dx / 2
  hdy: dy / 2

  edge: hdx + 0.5

  # easily change the thicknesses of different parts of the case
  bottom_case_height: 3
  top_case_height: 2.2
  battery_cover_height: 9

  mirrored_distance: 1.75 dx

points:
  zones:
    matrix:
      # Shift the PCB down and to the right to get it on the sheet in kicad
      anchor.shift: [25.5, -70]
      mirror:
        ref: matrix_inner_top
        distance: mirrored_distance
      key:
        tags: [switch]
      columns:
        outer:
          key:
            splay: -12.5
            kcol: P0
            mirror.kcol: P10
          rows:
            bottom:
              tags: [switch, low_bumper]
              krow: P6
            home:
              krow: P5
            top:
              orient: -5
              shift: [3.5, 1]
              tags: [switch, high_bumper]
              krow: P4
        pinky:
          key:
            stagger: -dx * 0.45
            kcol: P0
            mirror.kcol: P10
          rows:
            bottom:
              krow: P7
            home:
              krow: NFC2
            top:
              orient: -5
              shift: [3, 2]
              krow: NFC1
        ring:
          key:
            spread: 1.05 dx
            stagger: dx * 0.66
            splay: -5
            kcol: P1
            mirror.kcol: P9
          rows:
            bottom:
              krow: P6
            home:
              krow: P5
            top:
              krow: P4
        middle:
          key:
            spread: 1.04 dx
            stagger: hdx
            splay: -5
            kcol: P1
            mirror.kcol: P9
          rows:
            bottom:
              krow: P7
            home:
              krow: NFC2
            top:
              tags: [switch, mid_bumper]
              krow: NFC1
        index:
          key:
            stagger: -hdx
            splay: -2.5
            kcol: P2
            mirror.kcol: P8
          rows:
            bottom:
              krow: P6
            home:
              krow: P5
            top:
              krow: P4
        inner:
          key:
            stagger: -dx / 6
            kcol: P2
            mirror.kcol: P8
          rows:
            bottom:
              krow: P7
            home:
              krow: NFC2
            top:
              krow: NFC1

    # thumb zone
    thumbs:
      mirror:
        ref: matrix_inner_top
        distance: mirrored_distance
      key:
        tags: [switch]
        kcol: P3
      anchor:
        ref: matrix_index_bottom
        shift: [0, -dy - 2]
      columns:
        tucky.rows.spot:
          skip: true
        secondary.rows.spot:
          splay: -15
          origin: [-cx / 2, -cy / 2]
          tags: [opt_switch, low_bumper]
          krow: P6
          mirror.krow: P7
        primary.rows.spot:
          splay: -15
          origin: [-cx / 2, -cy / 2]
          krow: P5
          mirror.krow: NFC2
        reachy.rows.spot:
          splay: -15
          origin: [-cx / 2, -cy / 2]
          tags: [switch, thumb_bumper]
          krow: P4
          mirror.krow: NFC1

    # component zones
    mcu:
      anchor:
        aggregate.parts: [matrix_middle_top, mirror_matrix_middle_top]
        shift: [-6, 2.55]
      key:
        tags: [mcu]

    battery:
      anchor:
        ref: mcu
        shift: [6, -75]
        #columns.compartment.rows.cutout:
      key:
        tags: [battery]

    power:
      anchor:
        ref: mcu
        shift: [25, 8]
      key:
        tags: [power]

    reset:
      anchor:
        ref: power
        shift: [0, -12]
      key:
        tags: [reset]

    pad_xiao_pos:
      key.tags: [pad_circle, xiao_pos_pad]
      anchor:
        ref: mcu
        shift: [-6, -17]

    pad_reset:
      key.tags: [pad_circle, reset_pad]
      anchor:
        ref: pad_xiao_pos
        shift: [4, 0]

    pad_nfc1:
      anchor:
        ref: pad_reset
        shift: [4, 0]
      key:
        tags: [pad_circle, nfc_pad]
        kcol: NFC1

    pad_nfc2:
      anchor:
        ref: pad_nfc1
        shift: [4, 0]
      key:
        tags: [pad_circle, nfc_pad]
        kcol: NFC2

    jst:
      key.tags: [jst]
      anchor:
        ref: battery
        shift: [0, 30]
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

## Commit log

2026-05-13 gigas ready
    [battery_cover.stl, gigas.kicad_pcb, top_dovetail.stl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]
2026-05-17 chaski pcb ready
2026-05-18 chaski gerbers
2026-05-21 fix p chaski cases
    [battery_cover.stl, bottom_case.stl, mock_pcb.stl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]
2026-05-30 fix tolerances for 5-way switch cap
2026-06-03 refine case files for p gigas
    [rectangle_top_case_1_1.stl, rectangle_top_case_1_2.stl, rectangle_top_case_2_1.stl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]
2026-06-03 add joystick stl file
    [joystick.stl]
2026-06-06 reduce precision in stl files
    [battery_cover.stl, bottom_case.stl, mock_pcb.stl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]
2026-06-17 fix: NFC1 and NFC2 were mis-labeled on the PCB
    [chaski.kicad_pcb, gigas.kicad_pcb]
2026-07-18 add build guide for p chaski
    [mock_pcb.stl]
2026-07-18 update bom
2026-07-19 fix screw count
2026-07-30 gigas case 3D prints
    [bottom_case_cut_left.stl, bottom_case_cut_right.stl]
2026-07-30 Add links to makerworld printer profiles
2026-07-30 add info about makerworld print profiles
